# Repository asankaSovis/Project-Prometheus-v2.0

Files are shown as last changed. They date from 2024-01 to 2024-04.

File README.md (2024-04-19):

# 🔥 Project Prometheus v2.0
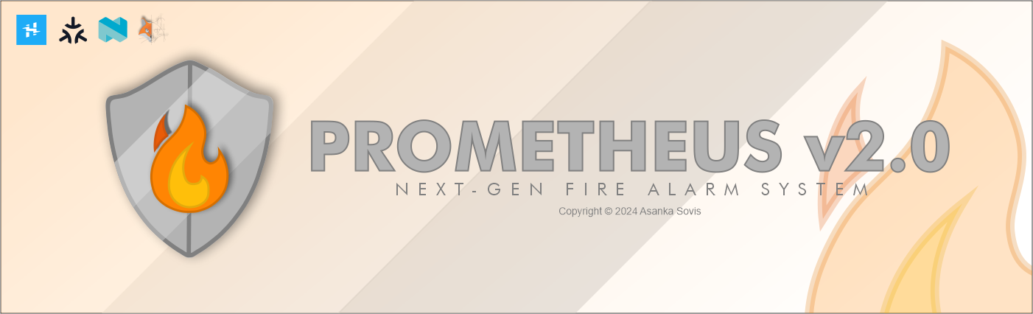
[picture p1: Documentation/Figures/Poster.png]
Poster

---

💸 Please consider donating on [Paypal](https://www.paypal.com/donate/?hosted_button_id=4EWXTWQ9FUFLA) to keep this project alive.

**Prometheus Fire Alarm System** is a fire alarm system and an extinguishing system that allows real-time monitoring via software. It can perform smart extinguishing on-site while simultaneously providing connectivity to multiple devices via the control panel. Prometheus is designed to be as simple and resilient as possible while making it safe to use and operate within a household.

**Prometheus 2.0** is the next generation of [Prometheus Fire Alarm System](https://github.com/asankaSovis/prometheus-fire-alarm); the future of household safety and monitoring. Developed on the nRF7002 platform, it brings all the features of v1.0 to the nRF platform along with additional features made possible by the nRF platform.

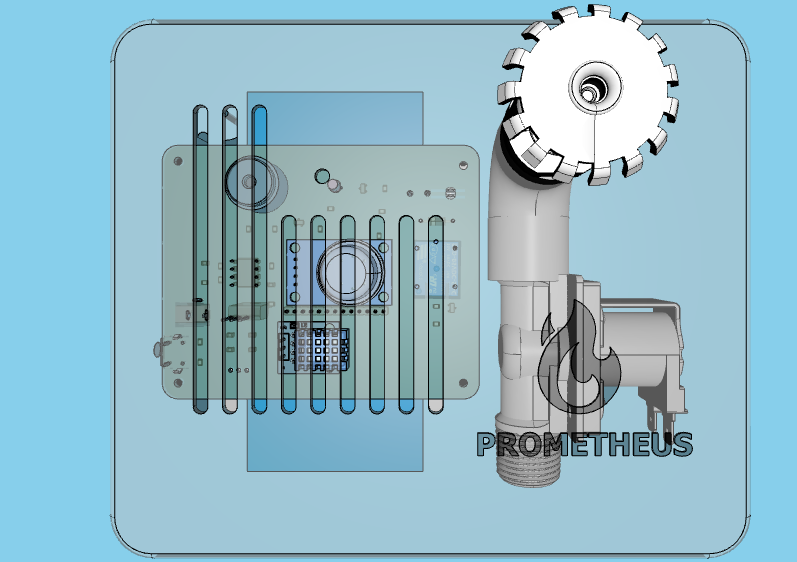
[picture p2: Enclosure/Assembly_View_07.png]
Assembly view
> 
> 3D view of the enclosure design

## 📜 License
> Project Prometheus v2.0 is licensed under the **GNU General Public License v3.0**.

Permissions of this strong copyleft license are conditioned on making available complete source code of licensed works and modifications, which include larger works using a licensed work, under the same license. Copyright and license notices must be preserved. Contributors provide an express grant of patent rights.

### Permissions
✔️ Commercial use | Modification | Distribution | Patent use | Private use

### Limitations
❌ Liability | Warranty

### Conditions
ℹ️ License and copyright notice | State changes | Disclose source | Same license 

Refer to the [License declaration](./LICENSE) for more details.

## 💾 Documentation
Please refer to the following links for different sections of documentation.

1. [Preface](./Documentation/Preface.md)
2. [Introduction](./Documentation/Introduction.md)
3. [Technical Specification](./Documentation/Technical_Specifications.md)
4. [Hardware Specification](./Documentation/Hardware_Specifications.md)
5. [Software Specification](./Documentation/Software_Specifications.md)
6. [Operational Details](./Documentation/Operational_Details.md)
7. [Project Management](./Documentation/Project_Management.md)
8. [Bill of Material](./Documentation/Bill_of_Material.md)
9. [References](./Documentation/References.md)
10. [Conclusion](./Documentation/Conclusion.md)

## 📊 Demonstration

> Prometheus Fire Alarm System - Demonstration (https://youtu.be/ORGNmy9aDy0 "Prometheus Fire Alarm System - Demonstration")
> Demonstration video of the final product

`© 2024 Asanka Sovis`

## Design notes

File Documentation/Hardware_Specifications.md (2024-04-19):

# Hardware Specification
The PCB of the Prometheus Fire Alarm System was designed and developed in-house. The PCB is a double layer PCB with sensors and indicators on the bottom and the rest of the components at the top. The PCB was manufactured and assembled by JLCPCB and the cost breakdown can be found in the [Bill of Material](./Bill_of_Material.md) section.
## Interface
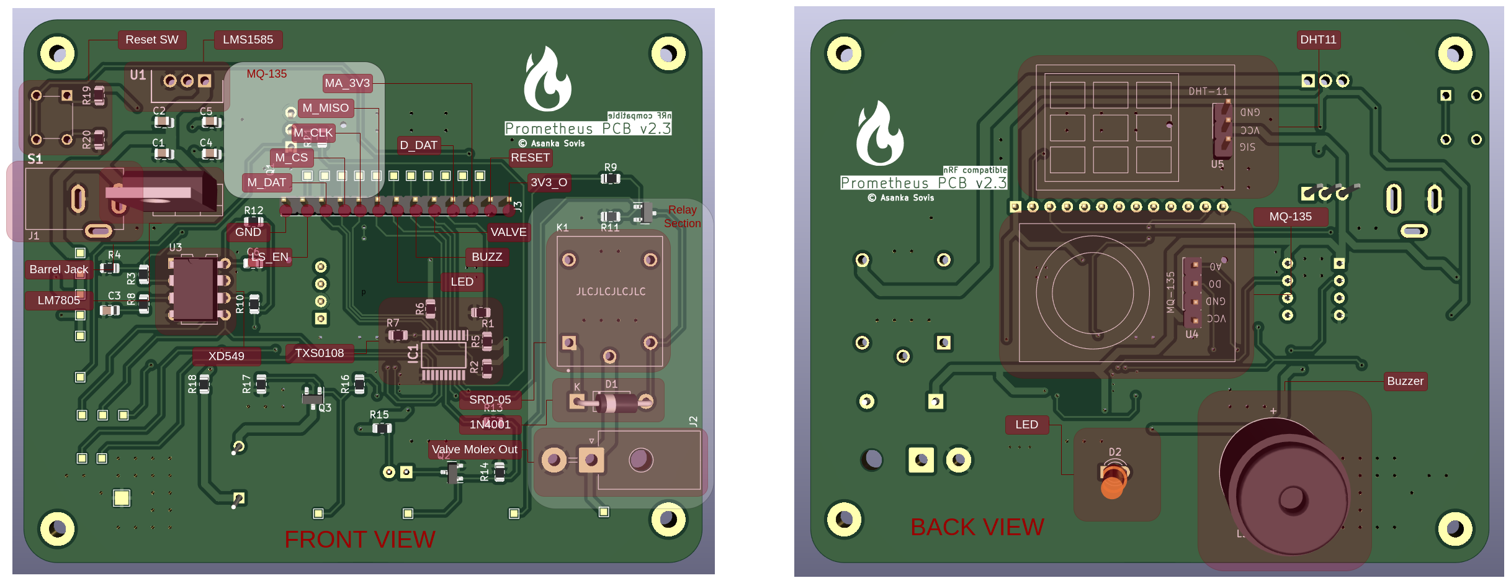
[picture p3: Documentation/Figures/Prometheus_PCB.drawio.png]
PCB layout on both sides
> 
> PCB layout on both sides

The interface between the Prometheus PCB and the nRF7002 DK is the most important part of the whole hardware design. This is why every control signal from the board is sent from a single location throughout the board. All of these signal have probing locations attached for debugging purposes. The pins are situated in the following order from left to right.

1. GND - Common ground.
2. LS_EN - Enable the level shifter. Active high, this pin has to be pulled up for the whole PCB to start working.
3. M_DAT - Digital out of the MQ-135 sensor. This is not used as the reading is sent through the ADC.
4. M_CS - Chip Select for the ADC recording the MQ-135 readings.
5. M_CLK - Clock signal for the ADC recording the MQ-135 readings.
7. M_MISO - Master In Slave Out for the ADC recording the MQ-135 readings.
8. LED - LED control signal.
9. BUZZ - Buzzer control signal.
10. VALVE - Valve control signal.
11. D_DAT - Data out of the DHT-11 sensor.
12. MA_3V3 - 5V analog output of the MQ-135 sent through a voltage divider to translate to a 3.3V output. This is here for experimental purposes and not used.
13. RESET - Reset signal from the reset button.
14. 3V3_O - 3.3V output to power the nRF7002 DK.

## Signalling
The nRF 7002 DK operates with standard 3.3V, however, the logic on the board is designed to operate in the 5V. This is because almost all the components used are 5V components. Thus all the logic goes through the TXS0108EQ Level Shifter. This translates the 3.3V signal from the nRF end to 5V on the PCB end and vice versa. The TXS0108EQ has the following structure.

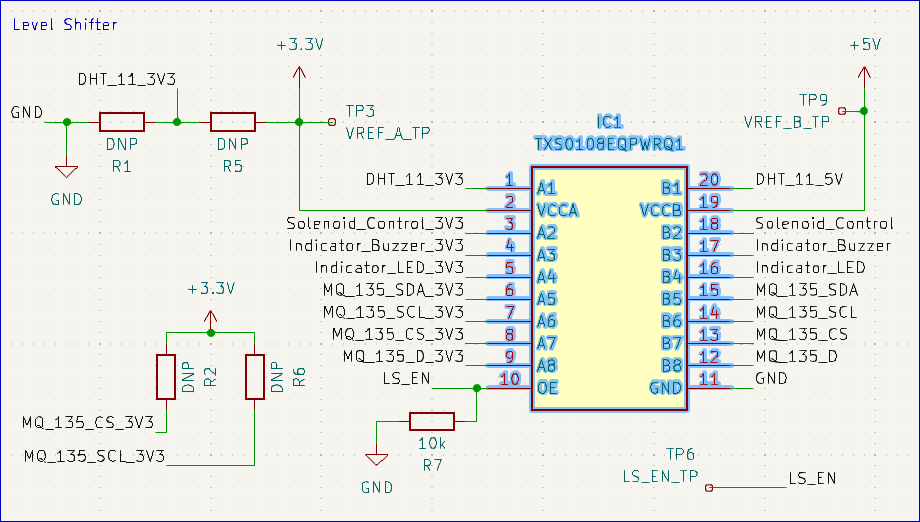
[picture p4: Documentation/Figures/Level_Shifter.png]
The structure of the level shifter layout on the PCB
> 
> The structure of the level shifter layout on the PCB

By enabling the chip by pulling the LS_EN up, we turn on the TXS0108EQ for communication with the PCB. Firmware details of this operation can be found in the [Software Specifications](./Software_Specifications.md) section.

## DHT-11 Reading
The DHT-11 uses UART to communicate with the controller. Therefore, the device only needs one data line to go to the microcontroller. As discussed, this line is simply routed through the level shifter to the nRF board.

## MQ-135 Reading
The MQ-135 is a bit more tricky. It has two signals coming out. One is the analog reading while the other is a digital one. Digital signal goes high when the analog signal reaches a certain threshold which can be set by the pot on the sensor itself. However, I wanted to get the analog reading to the nRF board and only use the digital pin as a backup.

Thus, the digital pin was simply routed through the level shifter and not used. This left me with the option of how to use the analog signal of the MQ-135. Using the ADC of the nRF means I have to step down the voltage to 3.3V which is not ideal for an analog signal. Therefore, I opted to use a voltage divider circuit just as another backup and sent this output directly to the nRF. However, if you check carefully, this is never used.

This is because I used a 5V ADC instead to take the reading of the MQ-135 and send it to the nRF as an SPI signal.

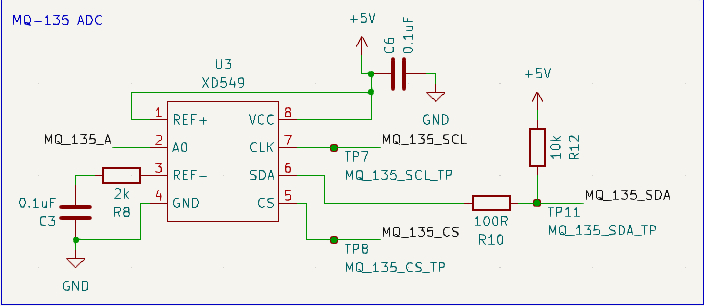
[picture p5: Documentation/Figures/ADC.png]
The XD549 ADC used for the MQ-135 analog signal
> 
> The XD549 ADC used for the MQ-135 analog signal

The XD549 is a 5V ADC and it sends the reading to the host controller as an SPI signal. For this we have three signal lines: CS, SDA (MISO) and CLK. Since the XD549 is a 5V device, these data lines have to be level shifted through the level shifter as well and since these are only carrying digital signals, there's no need to worry about shifting levels anymore. Firmware details of this operation can be found in the [Software Specifications](./Software_Specifications.md) section.

## Digital Output Devices
The PCB also features three digital IO devices. The buzzer and LED are quite straightforward and the circuit is simple. The signal from the nRF is passed through the level shifter to the IRLML6246 MOSFET and the MOSFET drives these two outputs.
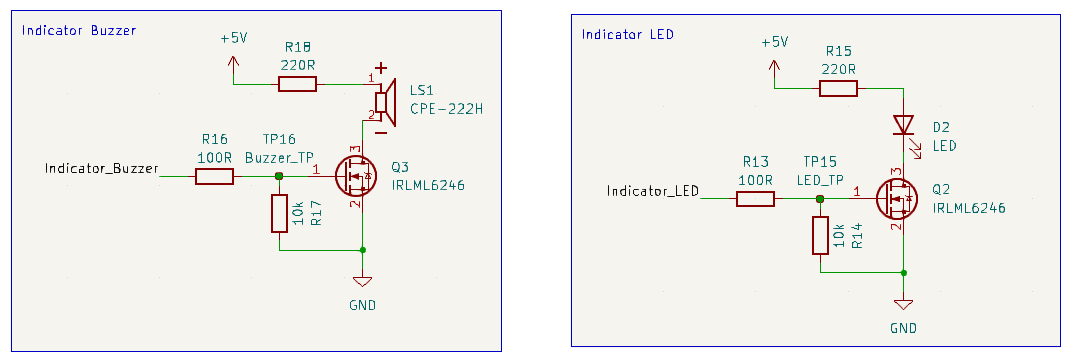
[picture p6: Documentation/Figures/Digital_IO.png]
Indicator LED and Buzzer design
> 
> Indicator LED and Buzzer design

The valve operates in pretty much the same way but the MOSFET does not drive the valve directly. The valve is a high current device and thus needs a relay for its operation. For this reason, the MOSFET drives a relay and that relay is what drives the valve in turn. The valve is connected via a MOLEX connector to the board.
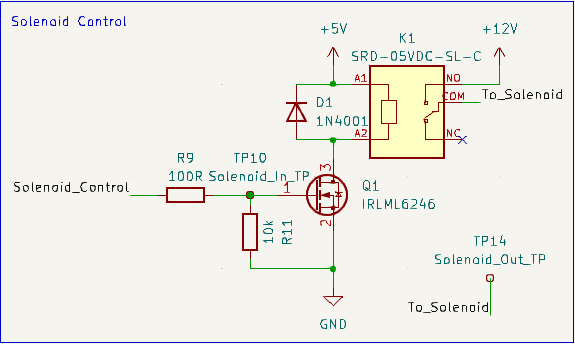
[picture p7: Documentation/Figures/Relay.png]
Valve control design
> 
>
> Valve control design

## Powering Up the System
The device needs to operate in three main voltage levels: 12V, 5V and 3.3V. The valve is controlled by a 12V signal, the nRF operates at 3.3V and the rest of the components operate at 5V. This means that 12V should come into the board as this is the highest required voltage level. In order to get the other two voltage levels, LM7805 and LMS1585 voltage regulators are used respectively for 5V and 3.3V. 
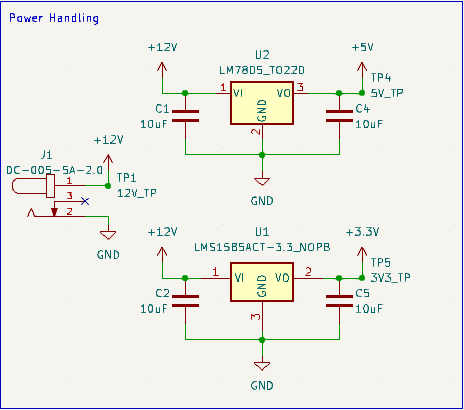
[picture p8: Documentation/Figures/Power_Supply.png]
Power supply for the PCB
> 
>
> Power supply for the PCB

The 12V can be provided through a 12V power supply and the device operates well below 500mA of current which makes it possible to use any 12V power supply. A typical power supply in this range comes with a barrel jack so the PCB has a barrel jack power input.

## Resetting the Device
The reset button simply connects the 3.3V to the reset of the nRF board. This allows for resetting the device from the PCB itself.

## The nRF 7002 DK
All required signals from the interface connect directly to the nRF 7002 DK as shown below.
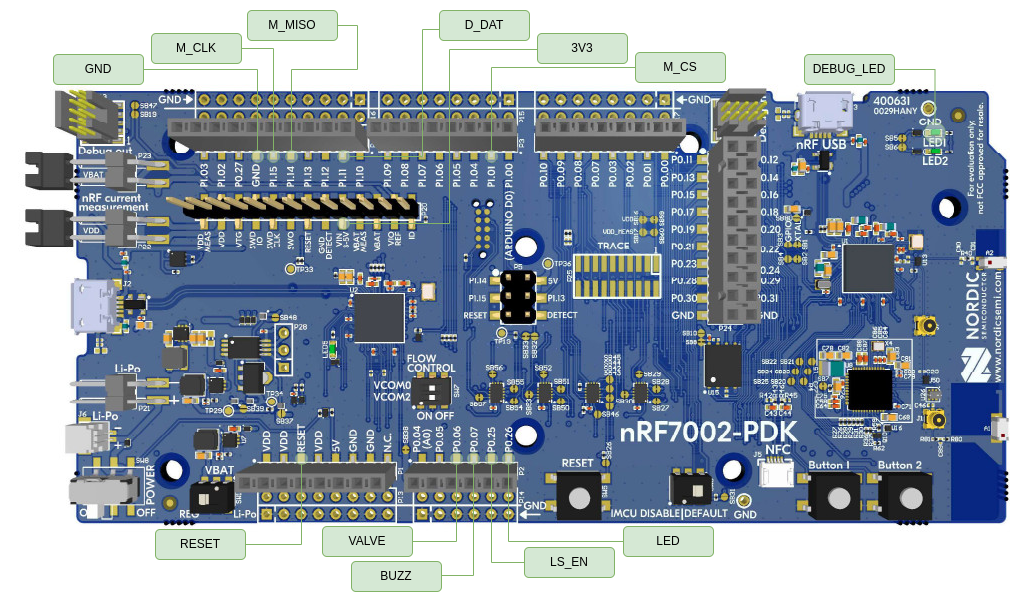
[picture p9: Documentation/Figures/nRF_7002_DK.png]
nRF 7002 DK interface pins
> 
> nRF 7002 DK interface pins *(Source: [developer.nordicsemi.com](https://developer.nordicsemi.com/nRF_Connect_SDK/doc/2.2.0/nrf/_images/nrf7002dk.jpg))*

The built-in LED 01 is also used for debug messaging. The default SPI line 3 of the SoC is used for the ADC while the rest of the GPIO was selected for convenience. 3.3V and GND from the power supply is also provided to the board from their respective pins. Additionally, the reset pin is also used however, in debug mode, this cannot be used. Firmware details of the operation of the nRF 7002 DK can be found in the [Software Specifications](./Software_Specifications.md) section.

## Schematic
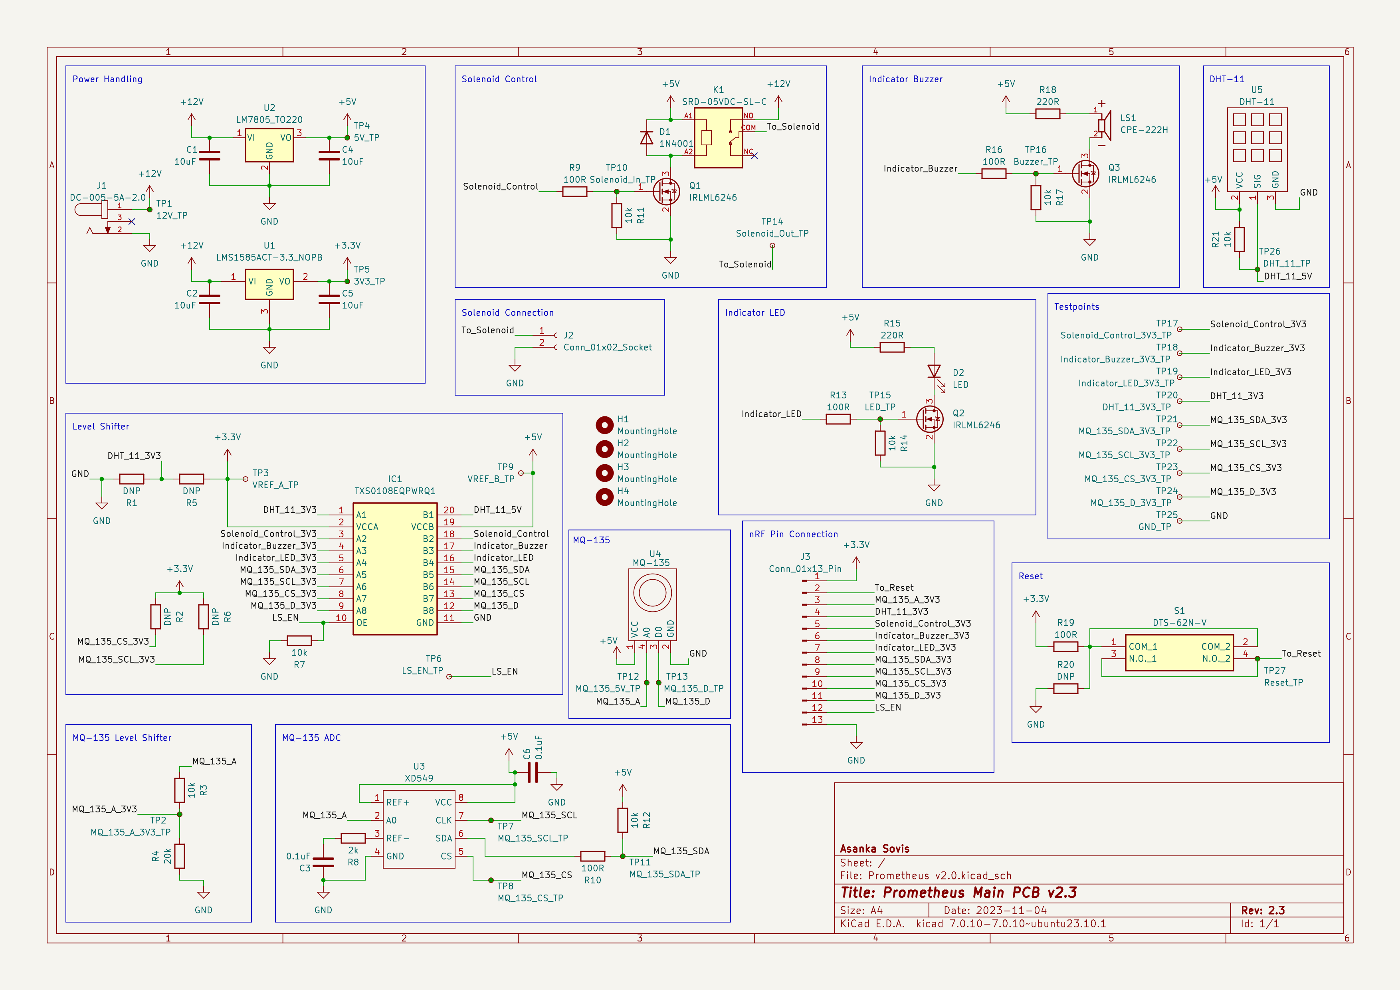
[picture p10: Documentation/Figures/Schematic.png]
The complete schematic view of the Prometheus PCB
> 
> The complete schematic view of the Prometheus PCB

The complete schematic of the PCB is given in the above diagram. This is available in the `Hardware/Prometheus v2.0` directory of the repository. The design was done using KiCad and all components used were available at JLCPCB at the time of manufacture. The complete Bill of Material and cost breakdown can be found in the [Bill of Material](./Bill_of_Material.md) section.

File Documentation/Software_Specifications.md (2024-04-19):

# Software Specification
The firmware of the Prometheus fire alarm system is developed entirely on the nRF Connect SDK. It uses Zephyr as the RTOS of choice and incorporates the device tree for hardware interfacing. It uses the SPI3 line of the nRF 5340 SoC for interfacing with the ADC. The rest of the IO connect to different signals in the PCB. The detailed breakdown is as follows.

- **GND -> GND** (Common grounding)
- **P1.15 -> M_CLK** (The clock of the  SPI 3 of the 5340 SoC to the Clock of the ADC)
- **P1.14 -> M_MISO** (MISO of the SPI 3 of the 5340 SoC to the SDA of the ADC)
- **P1.11 -> D_DAT** (Data signal from the DHT-11)
- **VIN 3-5V -> 3V3** (3.3V power supply to the nRF 7002 DK from the Prometheus PCB)
- **P1.01 -> M_CS** (Chip select GPIO from SoC to the CS of the ADC)
- **P0.26 -> LED** (GPIO to the LED control)
- **P0.25 -> LS_EN** (GPIO to the enable of the level shifter)
- **P0.07 -> BUZZ** (GPIO to the buzzer control)
- **P0.06 -> VALVE** (GPIO to the valve control)
- **RESET -> RESET** (Reset signal from the Prometheus PCB to the SoC)

The hardware layout of these pins within the Prometheus PCB and the nRF7002 DK can be found in the [Hardware Specifications](./Hardware_Specifications.md) section. Technical specification can be found in the [Technical Specifications](./Technical_Specifications.md). Additionally, the built-in LED 01 is used for debugging.

## Addressing and Configuration
The GPIO of the 5340 SoC has two 32bit GPIO addresses. Some of these are used internally, while the rest are usable. Each of the used pins are configured as follows.

- **P1.11** -> GPIO_PULL_UP | GPIO_ACTIVE_LOW
- **P0.25** -> GPIO_OPEN_SOURCE
- **P0.26** -> GPIO_OPEN_DRAIN
- **P0.06** -> GPIO_OPEN_DRAIN
- **P0.07** -> GPIO_OPEN_DRAIN
- **P1.01** -> GPIO_ACTIVE_HIGH | GPIO_OPEN_DRAIN

## Programming
The operation of the device starts with the initialization and checking if the device is ready. If not the built-in LED will periodically blink every second and try to reinitialize all components. Once done, the built-in LED will switch to flashing every ten second. At this stage, the sensor readings are read every 500ms and determined to see if critical levels are reached. If so, the warning is issued or valves are opened depending on the scenario. Additionally, if the user requested custom valve open or warning issue, this is also done. The operational flow chart of the device is given below.

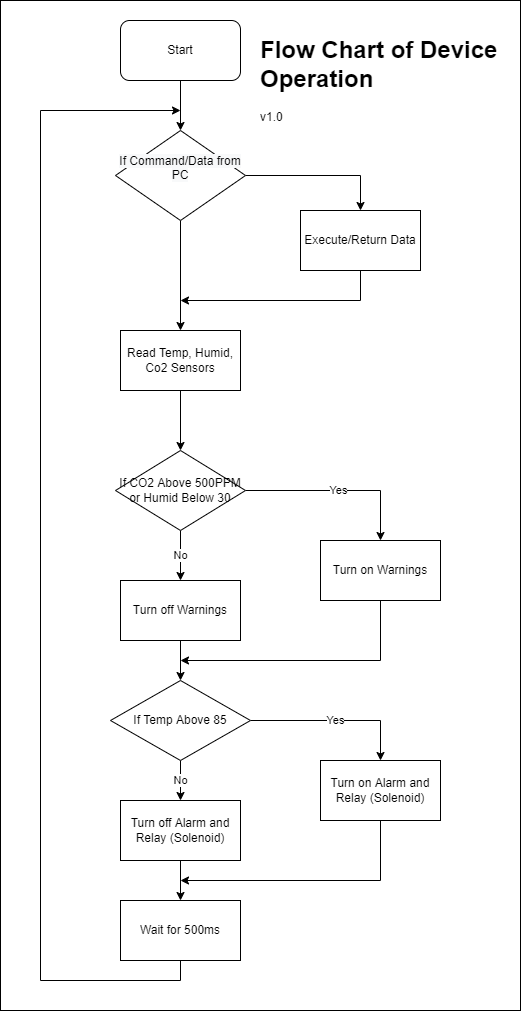
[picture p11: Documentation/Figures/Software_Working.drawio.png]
Operational flowchart of the device
> 
> Operational flowchart of the device

## Serial Protocol
The serial protocol is also an important aspect of the device. It allows the device to communicate with the Control Panel. All communication happen via the Micro USB interface of the nRF and USB port of a PC. The device communicate from its end via the COM ports while the device communicate from its end via the internal Zephyr UART. The communication is carried out in JSON. The communication protocol can be summed up as follows.
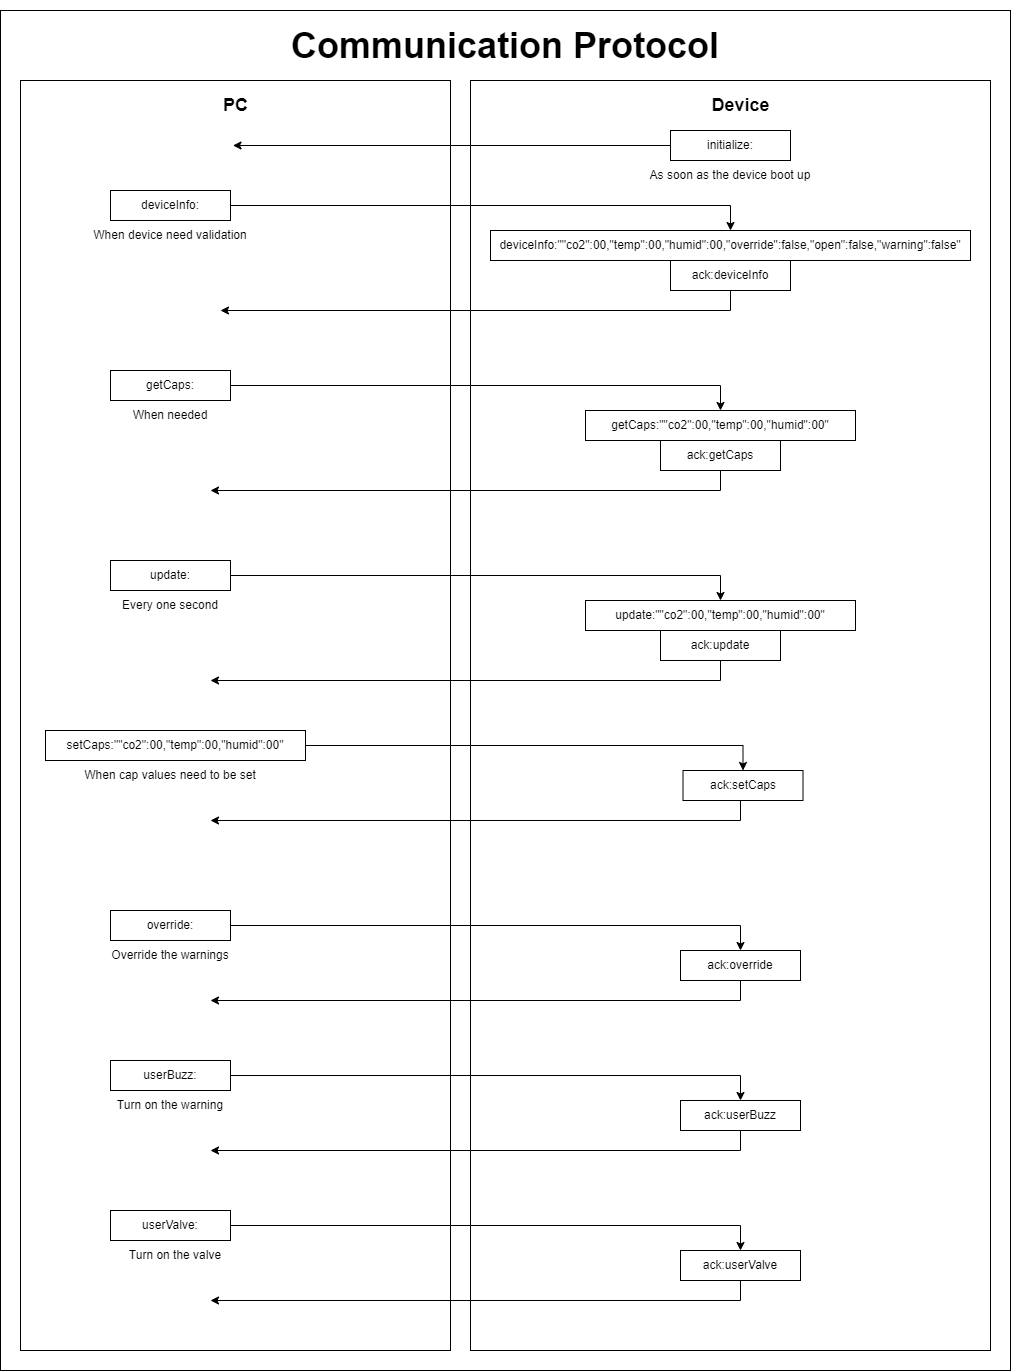
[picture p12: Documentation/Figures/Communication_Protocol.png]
Communication protocol
> 
> Communication protocol

## Monitoring and Controlling the Device
The Control Panel was written in C#. This program uses Windows APIs to connect to the COM ports of the computer to identify Prometheus devices connected. It has the following features.
- Connect multiple devices and add alias names to them for easy identification
- Monitor all sensor data from the devices from dedicated control panels
- Notifications for critical events
- Override warnings and control devices right from the PC
- Log sensor readings, visualize and export them
- Automatic reconnecting
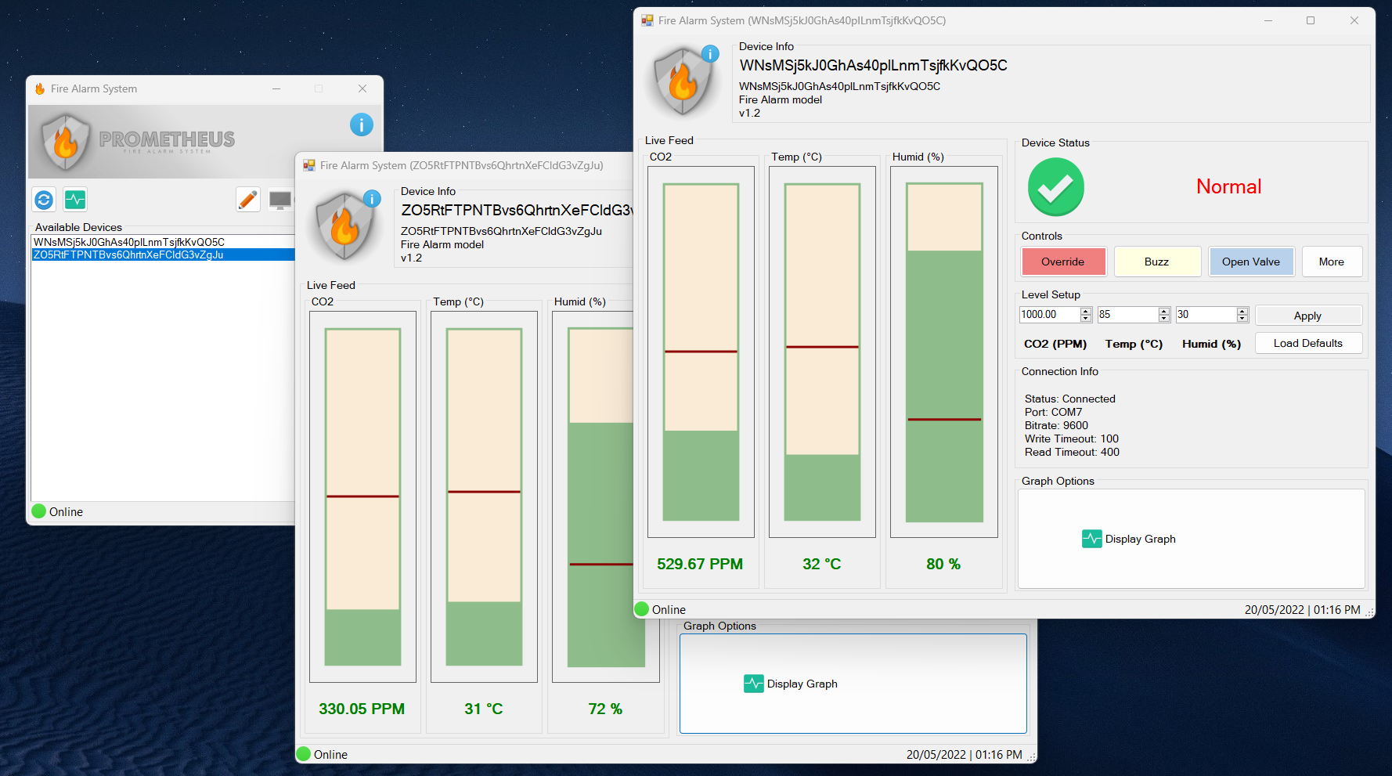
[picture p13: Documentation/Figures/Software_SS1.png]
> 
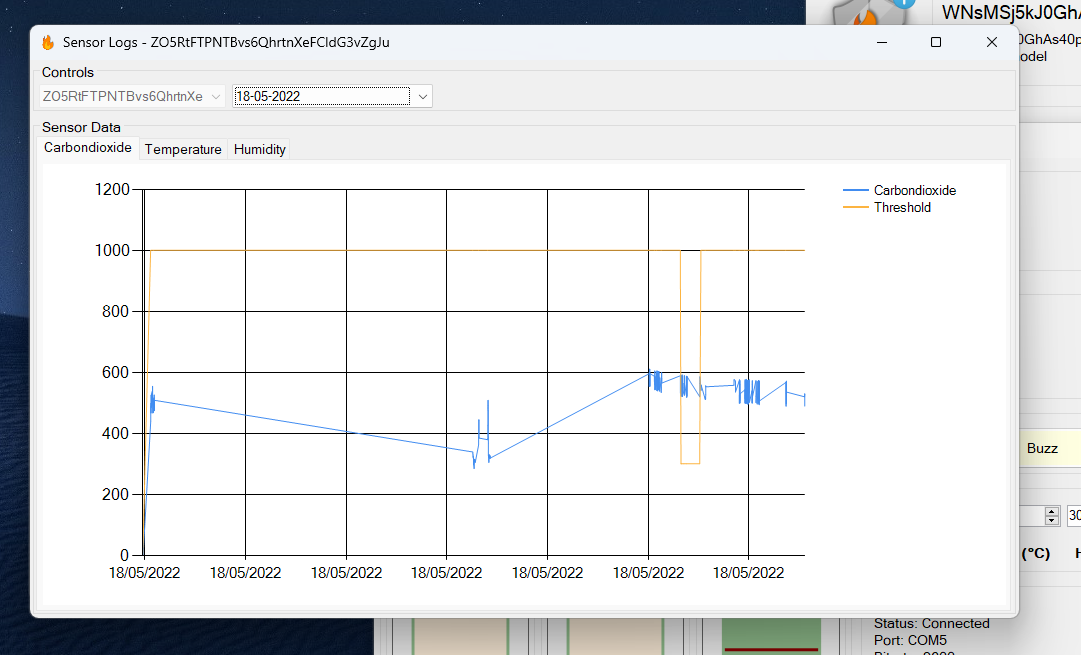
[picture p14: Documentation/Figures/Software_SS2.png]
> 
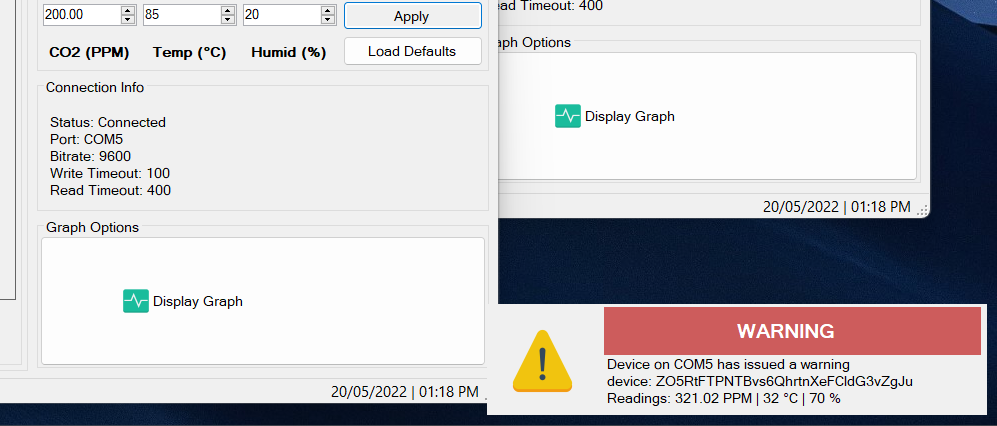
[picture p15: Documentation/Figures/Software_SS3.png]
> 
> Screenshots from the command panel

Further information on the project progress can be found in [Project Management](./Project_Management.md) section.

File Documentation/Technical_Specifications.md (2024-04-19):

# Technical Specifications
This section will discuss the overall technical specifications of the device. It includes each sensor/actuator/device categorized by what type of roll it performs along with the technical specifications. This section only includes the primary electronic items. For a comprehensive list of electronic components, please check the [Bill of Material](./Bill_of_Material.md). For operational details of the Prometheus Fire Alarm System, please refer to the [Operational Details](./Operational_Details.md) section.
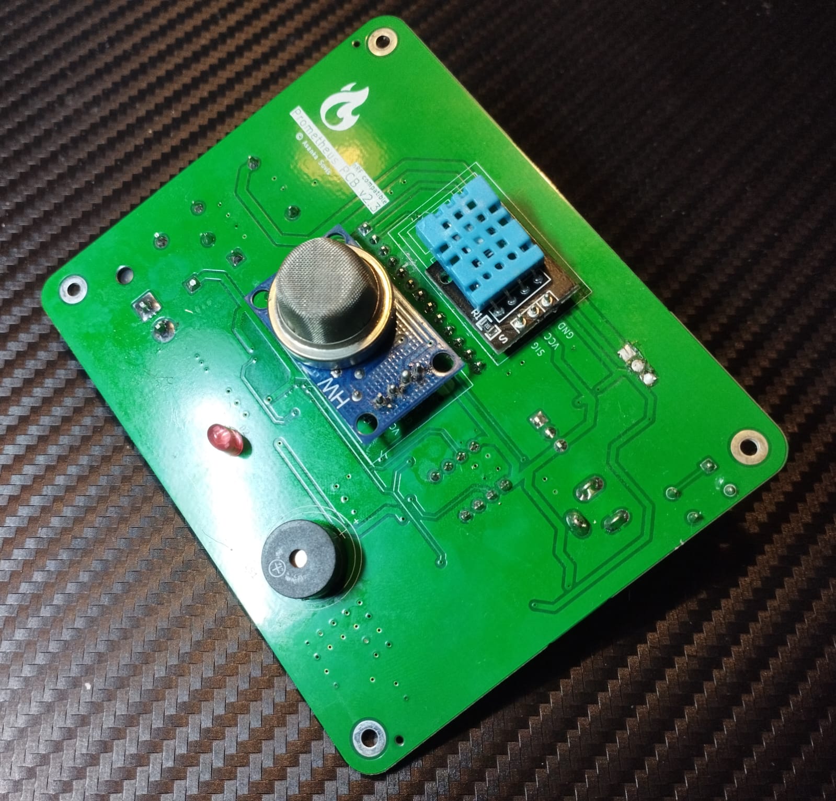
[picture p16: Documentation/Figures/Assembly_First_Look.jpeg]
First look at the assembly
> 
> First look at the assembly

## 1\. Control Unit
This is the brain of the system. It consists of an nRF7002dk which will be controlling the whole system. This also interfaces with all other components. With a dedicated nRF7002 Wi-Fi Companion IC and nRF5340 SoC, this is the ideal candidate for a project involving home automation and matter IoT device implementation.

### Specifications
#### nRF7002 - Low-power, advanced security, seamless coexistence
- 2\.4GHz and 5GHz Dual-band
- Low-power and Secure Wi-Fi for the IoT
- Ideal coexistence with Bluetooth LE
- Supported in nRF Connect SDK
- Wi-Fi 6 Station (STA)
- Complies with 802.11a/b/g/n/ac/ax
- 1 Spatial Stream (SS)
- 20 MHz channel bandwidth
- 64 QAM (MCS7), 86 Mbps PHY throughput
- OFDMA (Downlink and Uplink)
- BSS Coloring
- TWT
- SPI / QSPI
- Co-existence interfaces

#### nRF5340 SoC
- Dual-core Bluetooth 5.4 SoC supporting Bluetooth Low Energy, Bluetooth mesh, NFC, Thread and Zigbee
- 128 MHz Arm Cortex-M33 CPU with
- 1 MB Flash + 512 KB RAM
- 64 MHz Arm Cortex-M33 CPU with
- 256 KB Flash + 64 KB RAM
- Bluetooth Low Energy
- Bluetooth Direction Finding
- Bluetooth mesh
- Thread, Zigbee
- ANT
- NFC
- Advanced security
- USB, QSPI, HS-SPI
- 105 °C extended operating temperature
- 1\.7-5.5 V supply voltage range

## 2\. Fire Sensors
This is the module that directly interacts with the fire. This consists of two components as listed below.

### Specifications
#### Smoke Sensor – Detect the existence of a fire
- Operating Voltage: 2.5V to 5.0V
- Power consumption: 150mA
- Detect/Measure: NH3, Nox, CO2, Alcohol, Benzene, Smoke
- Typical operating Voltage: 5V
- Digital Output: 0V to 5V (TTL Logic) @ 5V Vcc
- Analog Output: 0-5V @ 5V Vcc

#### Temperature and Humidity Sensor – Detect the thermal changes in the surrounding
- Operating Voltage: 3.5V to 5.5V
- Operating current: 0.3mA (measuring) 60uA (standby)
- Output: Serial data
- Temperature Range: 0°C to 50°C
- Humidity Range: 20% to 90%
- Resolution: Temperature and Humidity both are 16-bit
- Accuracy: ±1°C and ±1%

They will sense the following three from the environment.
- Temperature – DHT11 sensor
- Humidity – DHT11 sensor
- Carbondioxide – MQ 135 sensor

DHT 11 communicates with the microcontroller digitally using UART while the MQ 135 senses analog and translates it to an SPI message via the ADC.

## 3\. Extinguisher
The extinguisher consists of three parts. It handles the extinguishing of the fire.

### Specifications
#### 5V relay – Convers the 5V control signal to 12V so that the solenoid valve can operate
- Supply voltage: 3.75V to 6V
- Quiescent current: 2mA
- Current when the relay is active: \~70mA
- Relay maximum contact voltage: 250VAC or 30VDC
- Relay maximum current: 10A

#### Solenoid Valve – Controls the water flow
- Material: Metal + plastic
- Voltage: DC 12V
- Power: 15W
- Current: 1.25A
- Inlet and outlet thread diameter: G1/2
- Pressure: 0.02 - 0.8Mpa
- Max fluid temperature: 80°C
- Operation mode: Normally Closed

#### Nozzle – Sprays the water onto the fire so that the extinguishing is effective
While the relay and valve were bought, the nozzle was custom-fabricated to suit the needs.

## 4\. Indicators
The indicators give an indication to the people about the fire. We included two indicators, both visual and auditory for the best outcome.

### Specifications
#### Visual – nRF7002dk Built-In LED
This LED indicates the technical status of the device. While initializing, the LED with be turned on. Once successful, it will flash every second to indicate that the device is actively monitoring. On an error, the LED will blink every second to indicate an error in the device.

#### Visual – Indicator red LED
The red LED will blink twice every second to indicate that the system is operating normally. If it stays continuously on, then there is a warning or extinguishing has started. Any other combination or no light at all means that the device is turned off or is not working properly.

#### Auditory – A 5V Buzzer
The buzzer stays off when the system is operating normally. It will beep once every second in case a warning is issued. It will then continuously buzz in case of an extinguishing.

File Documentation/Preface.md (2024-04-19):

# Preface
One of the key requirements for a smart home is the safety and well-being of the inhabitants.  This is why it's important to have devices to actively monitor and rectify any threats that occur within the house. One such threat is the hazard of fire. According to the WHO, more than 300,000 deaths occur every year due to fire-related hazards [1](https://scholar.google.com/scholar_lookup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,+1991-1995&author=CfD+Control&volume=47&issue=38&publication_year=1998&pages=803-6&pmid=9776167&).

Thus we see the importance of incorporating a fire monitoring and extinguishing system into the modern smart home. This should actively monitor the environment for critical changes in the levels of humidity, temperature and carbon dioxide and take necessary precautions to rectify any fires that get detected. The residents should also get the convenience of actively monitoring the state of the alarm and extinguishing system whenever they require it. This is the premise of the Prometheus Fire Alarm System v2.0.

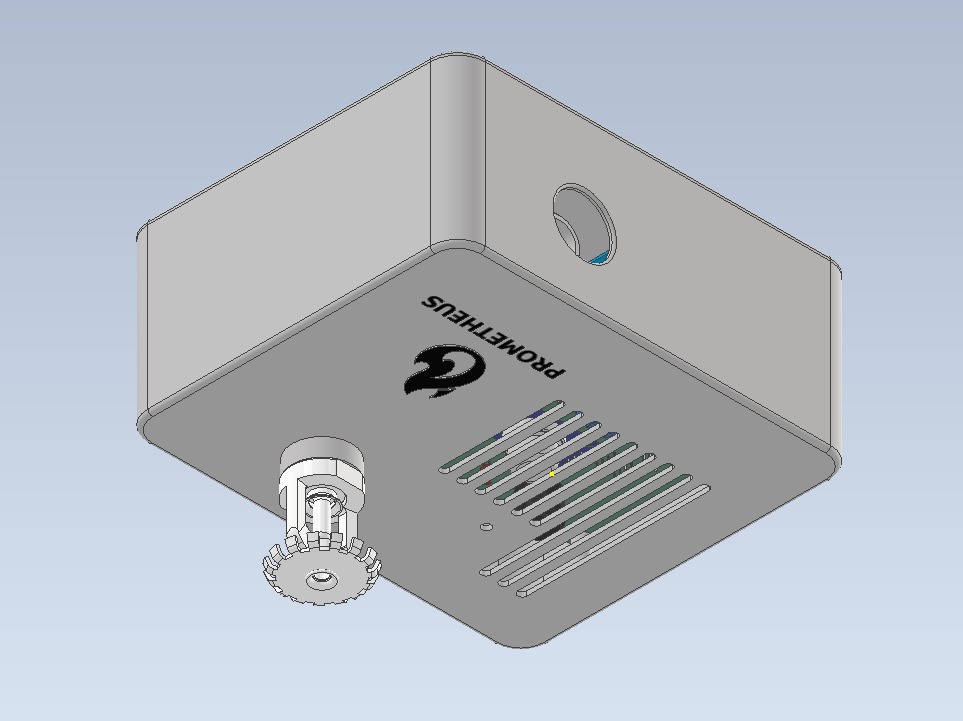
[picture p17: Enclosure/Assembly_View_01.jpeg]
Final assembly render
> 
> Final assembly render

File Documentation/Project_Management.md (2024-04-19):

# Project Management
## Development So Far
The project started with a proposal outlining the problem, intended solution and its development strategy. This can be found in the [Project Prometheus v2.0](./Project_Prometheus_v2.0.md) document. Using this, hardware request was applied on September 20, 2023. On September 25, 2023 an email was received with the news that the Prometheus Fire Alarm System v2.0 was selected as a recipient for free hardware.

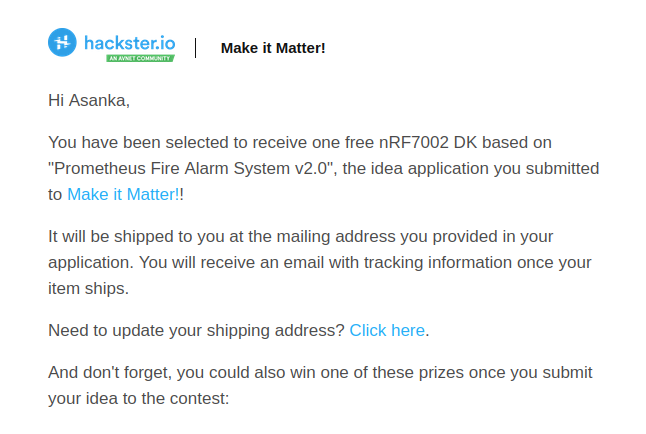
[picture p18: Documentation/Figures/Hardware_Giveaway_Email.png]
Email received announcing the selection to receive hardware
> 
> Email received announcing the selection to receive hardware

With this, a project timeline was created to better optimize the limited time I have. 

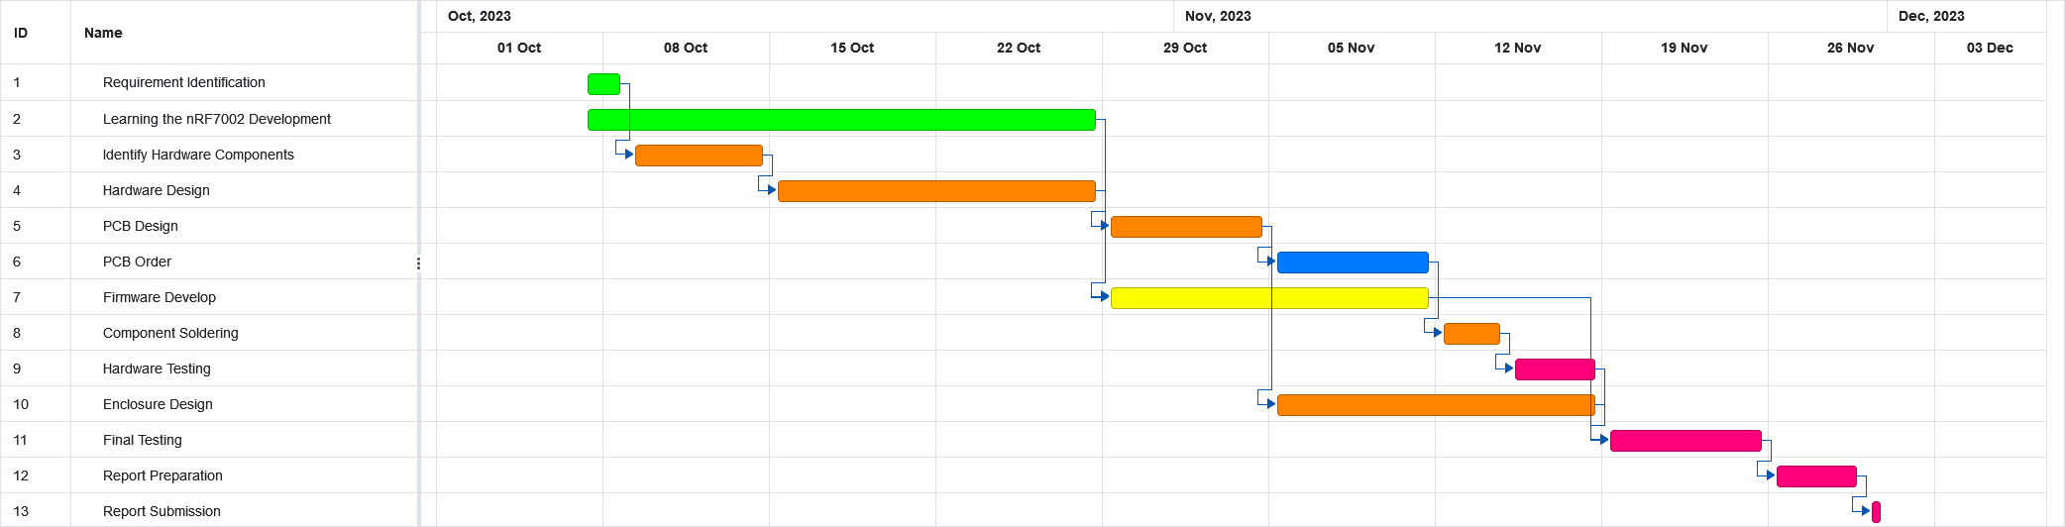
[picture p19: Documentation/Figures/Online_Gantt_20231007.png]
Project timeline
> 
> Project timeline

However, keeping up with this schedule proved to be extremely hard as I was treading in new territory. Thanks to the extension provided until January 14, 2024, the project managed to continue on. The final report was submitted on January 14, 2024.

## Project Status
After the final submission of the report, the state of the project is as follows.

- Requirement identification ✔️
- Learning the nRF 7002 development ♻️
- Identify hardware components ✔️
- Hardware design ✔️
- PCB design ✔️
- PCB order ✔️
- Firmware development ✔️
- Integrating matter protocol ♻️
- Component soldering ✔️
- Hardware testing ✔️
- Enclosure design ✔️
- Final testing  ♻️
- Report preparation ✔️
- Report submission ✔️

## Identified Issues with the Project
The following issues are mainly highlighted after analyzing the current state of the project.

- Unpublished articles in the Hashnode backlog
- Damaged MQ-135 sensor while hardware testing
- Matter integration incomplete
- Not enough knowledge and experience with nRF
- Not enough testing completed

## Future of the Project
After a small break from the project, my plan is to start rectifying these issues and adding more features to the design.

- Complete the [nRF Connect SDK Fundamentals](https://academy.nordicsemi.com/courses/nrf-connect-sdk-fundamentals/) course
- Complete integrating matter protocol to the project
- Replace MQ-135 gas sensor
- Replace DHT11 with Bosch BME280
- Publish and complete backlog of Hashnode articles
- Continue testing the system
- Write redesigned command panel using Flutter to be cross-platform and supporting both serial communication and matter network

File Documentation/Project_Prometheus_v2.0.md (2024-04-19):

# Introduction
One of the key requirements for a smart home is the safety and well-being of the inhabitants.  This is why it's important to have devices to actively monitor and rectify any threats that occur within the house. One such threat is the hazard of fire. According to the WHO, more than 300,000 deaths occur every year due to fire-related hazards [1].

Thus we see the importance of incorporating a fire monitoring and extinguishing system into the modern smart home. This should actively monitor the environment for critical changes in the levels of humidity, temperature and carbon dioxide and take necessary precautions to rectify any fires that get detected. The residents should also get the convenience of actively monitoring the state of the alarm and extinguishing system whenever they require it. This is the premise of the Prometheus Fire Alarm System v2.0.

## Prometheus v1.0
The idea of a fire alarm system has already been implemented in the form of Prometheus Fire Alarm System v1.0. This version aimed at developing a cost-effective monitoring and extinguishing system that is robust and scalable. The following were the targets of this project:

1. **Cost** - Develop a system based on off-the-shelf components that are cost-effective
2. **Scalable** - Availability for multiple monitoring devices to operate and synchronize in real-time
3. **Independent** - Whether connected or not, the device should monitor and react on its own without the involvement of the operator

## What's Next?
The next step would be to improve the Prometheus Fire Alarm System into a smart home device, bringing in the cost-effective, independent and scalable fire alarm and extinguishing system to the smart home. This will allow it to sit alongside other sensors and systems to provide all the smart homes with safety from fire.

The improvements thus suggested will be as follows.

1. Add a built-in charging system to allow the system to run when even the power is lost
2. Redesign the system to use the **nRF7002** chip instead of an ATMega
3. Rewrite the firmware to incorporate the Matter protocol

## Further Information
[Prometheus Fire Alarm System Firmware Repo](https://github.com/asankaSovis/prometheus-fire-alarm/tree/main)
[Prometheus Command Panel Repo](https://github.com/asankaSovis/prometheus-command-panel)
[Prometheus Fire Alarm System v1.0 Report](https://github.com/asankaSovis/prometheus-fire-alarm/blob/main/Additional%20Material/Engineering%20Design%20Project%20-%20Project%20Report.pdf)
[Prometheus Fire Alarm System Demo Video (Youtube)](https://youtu.be/5h3k6kufkHo?si=pq6S2FBMBYGGU_1R)

## References
[1] https://scholar.google.com/scholar_lookup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,+1991-1995&author=CfD+Control&volume=47&issue=38&publication_year=1998&pages=803-6&pmid=9776167&
[2] https://www.co2meter.com/blogs/news/15164297-co2-gas-concentration-defined
[3] https://science.howstuffworks.com/environmental/earth/geophysics/fire.htm

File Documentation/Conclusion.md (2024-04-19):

# Conclusion
Project Prometheus v2.0 turned into such an exciting and inspiring pet project for me. It encouraged me to learn so many new things and to experiment with things that I never would've had access to before. On this submission day, I'm confident about what I managed to achieve with this project. Prometheus came so far; yet there's more to look forward to. I'm excited and looking forward to seeing where Project Prometheus will go in the future. After a small break, I will be back with its development.

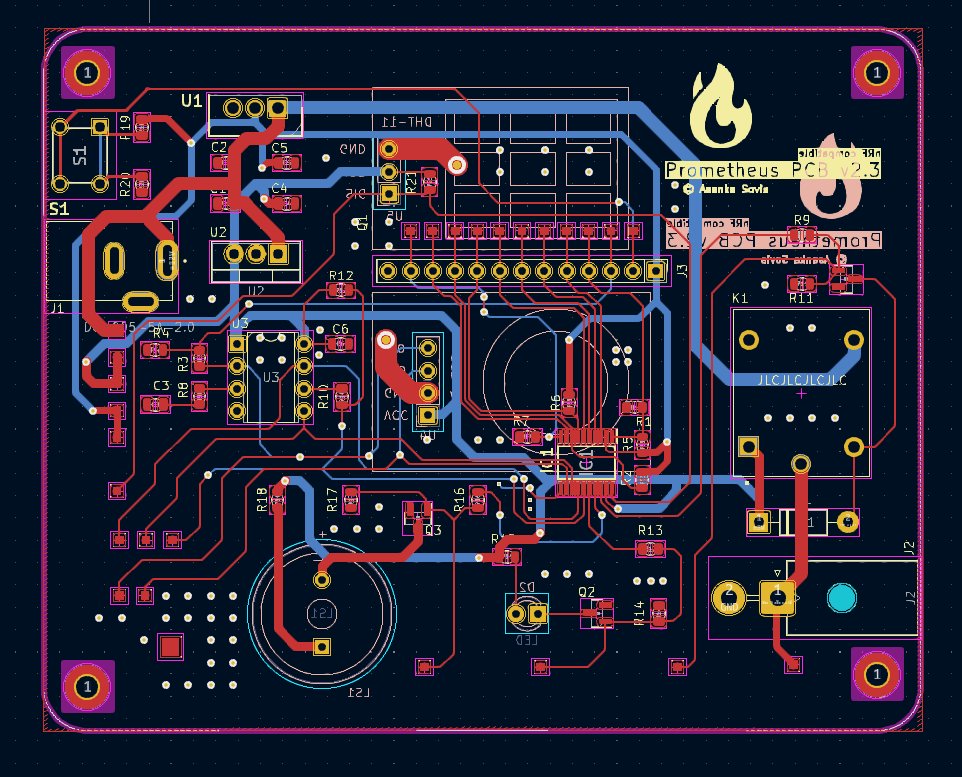
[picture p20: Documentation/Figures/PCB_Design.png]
> 
> View of the PCB design of Prometheus PCB

## Thanks
This four-month journey was a journey filled with a lot of ups and downs. I would not be able to achieve this level of improvement without the help of countless people. The biggest support came from the people at my former workplace who encouraged, advised, continuously asked about the progress and even offered technical guidance and help.
This goes without mentioning the awesome people who helped me whenever I posted dumb questions on the [Nordic DevZone](https://devzone.nordicsemi.com/) forum and Discord server. Thank you for tolerating my newbie questions and annoying mistakes.

Thanks to the people who had been posting content on Youtube and other platforms guiding people through Matter, the nRF platform, Zephyr and related fields. Without you, this project would not be able to flourish.
Finally to the awesome people at Nordic Semiconductors and Hackster.io for organizing such a valuable opportunity. I would never have been able to afford to own something like nRF7002 DK if not for this project. Thank you for allowing me to enter into this world of innovative technology.

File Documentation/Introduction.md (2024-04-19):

# Introduction
> 3D view of the enclosure design
> 3D view of the enclosure design

**Prometheus Fire Alarm System** is a fire alarm system and an extinguishing system that allows real-time monitoring via software. It can perform smart extinguishing on-site while simultaneously providing connectivity to multiple devices via the control panel. Prometheus is designed to be as simple and resilient as possible while making it safe to use and operate within a household.

**Prometheus 2.0** is the next generation of [Prometheus Fire Alarm System](https://github.com/asankaSovis/prometheus-fire-alarm); the future of household safety and monitoring. Developed on the nRF7002 platform, it brings all the features of v1.0 to the nRF platform along with additional features made possible by the nRF platform.

> First demo of the Prometheus Fire Alarm System v2.0 in operation (https://youtu.be/ORGNmy9aDy0 "Prometheus Fire Alarm System - Demonstration")
> First demo of the Prometheus Fire Alarm System v2.0 in operation

## Project Overview
The project spanned from October 5, 2023, to January 14, 2024. Since, enrolling on the project, I have been tirelessly working on the development of the Prometheus Fire Alarm System. Since its inspection, it has been one of my pet projects that I did in my free time after completing it as a project for the university. It brought me a lot of knowledge, experience and fun. The Make it Matter contest had been a great opportunity for me to share my pet project with the world, and to integrate it with a well-renowned platform such as the nRF platform.
Juggling between academic work, full-time employment and personal life, I am proud of my achievements. However that I have come up with. However, I still feel like there's a long way for Prometheus to go.

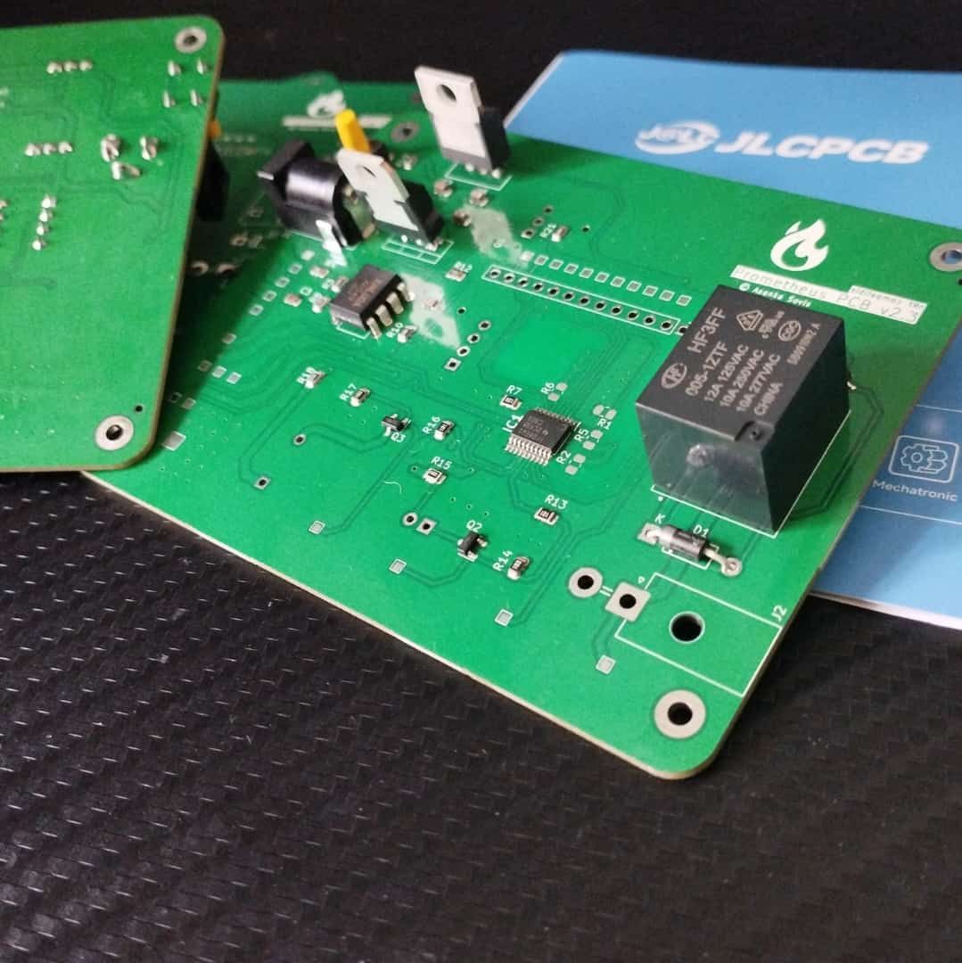
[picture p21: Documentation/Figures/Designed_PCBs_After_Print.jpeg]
First look at the Prometheus PCB v2.0 after arriving from JLCPCB
> 
> First look at the Prometheus PCB v2.0 after arriving from JLCPCB

## The Journey and the Future
The journey started without any idea about Nordic, nRF or Matter. With limited access to resources and a limited budget, the project continued with days of researching online to discussing in online forums. However, with this limited budget and time, I am proud of what I've achieved. It had been a great opportunity to work with the nRF platform.

This will not be the end of my journey with Nordic or the nRF platform as I have planned to continue the devlog of the Prometheus Project. I also have tutorials planned on the issues I faced while working on this platform. One of the biggest hurdles I faced was the limited availability of resources online and outdated information. nRF and Matter are evolving rapidly but the internet has not yet been able to keep up with this growth and expansion. I'd like to pay my part and share my knowledge with others in hopes that they might not run into the same issues that I had to face.

In terms of Project Prometheus, there is a lot of work planned, even after the end of the **Make it Matter** contest. And I welcome everyone to continue the journey on [my Blog](https://asanka.hashnode.dev/).

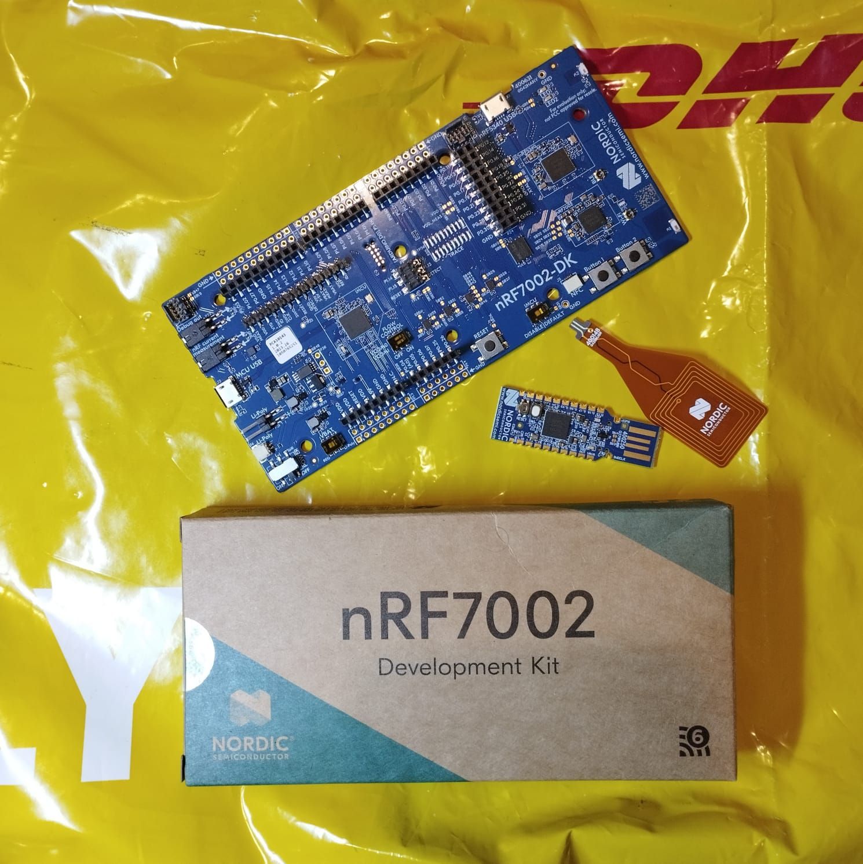
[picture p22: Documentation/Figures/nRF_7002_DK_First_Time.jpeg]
First look at the nRF7002 DK
> 
> First look at the nRF7002 DK

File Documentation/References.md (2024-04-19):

# References
## Internal References

- [Prometheus Fire Alarm System v2.0 - First Prototype](https://youtu.be/ORGNmy9aDy0?si=K__lnq3Fp0OjW0Gl)
- [Project Prometheus v2.0 Repository](https://github.com/asankaSovis/Project-Prometheus-v2.0)
- [Prometheus Fire Alarm System Repository](https://github.com/asankaSovis/prometheus-fire-alarm)
- [Prometheus Command Panel](https://github.com/asankaSovis/prometheus-command-panel)
- [Asanka Sovis - Github Profile](https://github.com/asankaSovis)
- [Asanka Sovis - Website](https://asankasovis.github.io/)
- [Asanka Sovis - LinkTree](https://linktr.ee/asankasovis)
- [Asanka Sovis - LinkedIn](https://www.linkedin.com/in/asanka-sovis/)
- [Asanka Sovis - X (Formerly Twitter)](https://twitter.com/AsankaSovis)
- [Asanka Sovis - Hashnode Blog](https://asanka.hashnode.dev/)
- [Asanka Sovis - Blogspot](https://asanka-sovis.blogspot.com/)
- [Asanka Sovis - Hackster.IO Profile](https://www.hackster.io/AsankaSovis)

## External References
- [Getting started with nRF7002 DK](https://developer.nordicsemi.com/nRF_Connect_SDK/doc/2.2.0/nrf/ug_nrf7002.html)
- [Zephyr Project Documentation](https://docs.zephyrproject.org/latest/index.html)
- [Hackster.IO - Make It Matter Contest](https://www.hackster.io/contests/makeitmatter)
- [Alphatronic Store](https://alphatronic.lk/)
- [Nordic DevZone](https://devzone.nordicsemi.com/)
- [nRF Connect SDK Documentation](https://infocenter.nordicsemi.com/index.jsp?topic=%2Fug_nrf7002_dk%2FUG%2Fnrf7002_DK%2Fintro.html)
- [JLCPCB SMT Parts Library](https://m.jlcpcb.com/more/partsLibrary)
- [nRF 5340 SoC Documentation](https://www.nordicsemi.com/Products/nRF5340)
- [nRF7002 Wi-Fi 6 Companion IC Documentation](https://www.nordicsemi.com/Products/nRF7002)
- [nRF7002 DK Documentation](https://www.nordicsemi.com/Products/Development-hardware/nRF7002-DK)
- [Matter over Thread with NRF52](https://abluethinginthecloud.com/matter-over-thread-with-nrf52/)
- [Circuit Dojo Youtube Channel](https://www.youtube.com/@CircuitDojo)
- [The Linux Foundation Youtube Channel](https://www.youtube.com/@LinuxfoundationOrg)
- [The Zephyr Project Youtube Channel](https://www.youtube.com/@ZephyrProject)
- [Nordic Semiconductor Youtube Channel](https://www.youtube.com/@NordicSemi)
- [WSN & IoT Youtube Channel](https://www.youtube.com/@wsniot)
- [nRF Connect SDK Fundamentals](https://academy.nordicsemi.com/courses/nrf-connect-sdk-fundamentals/)

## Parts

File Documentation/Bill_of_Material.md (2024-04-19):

# Bill of Material
This includes a comprehensive list of all the individual electronic and non-electronic components used in the manufacture of the Prometheus Fire Alarm System. For an overall specification of the sensors, actuators and controllers; please refer to the [Technical Specifications](./Technical_Specifications.md) section.

1. [10uF Capacitors](<## 10uF Capacitors - Quantity 4>)
2. [0\.1uF Capacitors](<## 0.1uF Capacitors - Quantity 2>)
3. [10kΩ Resistors](<## 10kΩ Resistors - Quantity 7>)
4. [100Ω Resistors](<## 100Ω Resistors - Quantity 5>)
5. [220Ω Resistors](<## 220Ω Resistors - Quantity 2>)
6. [20kΩ Resistors](<## 20kΩ Resistors - Quantity 1>)
7. [2kΩ Resistors](<## 2kΩ Resistors - Quantity 1>)
8. [1N4001 Diode](<## 1N4001 Diode - Quantity 1>)
9. [Through Hole LED](<## Through Hole LED - Quantity 1>)
10. [LMS1585 Voltage Regulator](<## LMS1585 Voltage Regulator - Quantity 1>)
11. [LM7805 Voltage Regulator](<## LM7805 Voltage Regulator - Quantity 1>)
12. [XD549 ADC](<## XD549 ADC - Quantity 1>)
13. [MQ-135 Gas Sensor](<## MQ-135 Gas Sensor - Quantity 1>)
14. [DHT-11 Temperature/Humidity Sensor](<## DHT-11 Temperature/Humidity Sensor - Quantity 1>)
15. [IRLML 6246 MOSFET](<## IRLML 6246 MOSFET - Quantity 3>)
16. [TXS0108EQ Level Shifter](<## TXS0108EQ Level Shifter - Quantity 1>)
17. [SRD-05 Relay](<## SRD-05 Relay - Quantity 1>)
18. [CPE-222H Buzzer](<## CPE-222H Buzzer - Quantity 1>)
19. [DTS-62 Horizontal Switch](<## DTS-62 Vertical Switch - Quantity 1>)
20. [XKB DC-005 Barrel Jack Connector](<## XKB DC-005 Barrel Jack Connector - Quantity 1>)
21. [2x1 Molex Connector](<## 2x1 Molex Connector - Quantity 1>)
22. [1x13 Pin Header](<## 1x13 Pin Header - Quantity 1>)
23. [nRF 7002 DK Development Board](<## nRF 7002 DK Development Board - Quantity 1>)
24. [12V Power Supply with DC Barel Jack](<## 12V Power Supply with DC Barel Jack - Quantity 1>)
25. [Micro USB Cable](<## Micro USB Cable - Quantity 1>)
26. [1x13 Male to Female Ribbon Cable](<## 1x13 Male to Female Ribbon Cable - Quantity 1>)
27. [ZE-4F180 Valve with compatible tubing and spray end](<## ZE-4F180 Valve with compatible tubing and spray end - Quantity 1>)

## Cost Breakdown
The nRF 7002 DK was recieved from the hardware giveaway program saving me around $56.49. (Rs. 18, 189.30) The direct cost was only involved with PCB manufacturing, assembly and shipping. Overall, the cost breakdown is as follows.
- nRF 7002 DK: $0.00
- PCB Printing: $4.00
- Setup fee: $8.00
- Stencil: $1.50
- Components: $15.12
- Extended components fee: $25.48
- SMT Assembly: $0.46
- Hand-soldering labor fee: $3.50
- Manual Assembly: $0.96
- Refund: -$0.06

This adds a merchandise total of $58.96 (Rs. 18, 984.62)
- MERCHANDISE TOTAL: $58.96 (Rs. 18, 984.62)
- SHIPPING CHARGE: $25.90 (Rs. 8, 339.58)
- DISCOUNT: - $10.00 (Rs. 3, 219.92)
- ORDER TOTAL: $74.86 (Rs. 24, 104.28)

This finally gives a total of $74.86 (Rs. 24, 104.28). Adding government taxes of Rs. 8, 000 ($24.85) gives a final expense of $99.71 (Rs. 32, 104.28).
- ORDER TOTAL: $74.86 (Rs. 24, 104.28)
- GOVERNMENT TAXES: $24.85 (Rs. 8, 000)

- **FINAL DIRECT COST: $99.71 (Rs. 32, 104.28)**
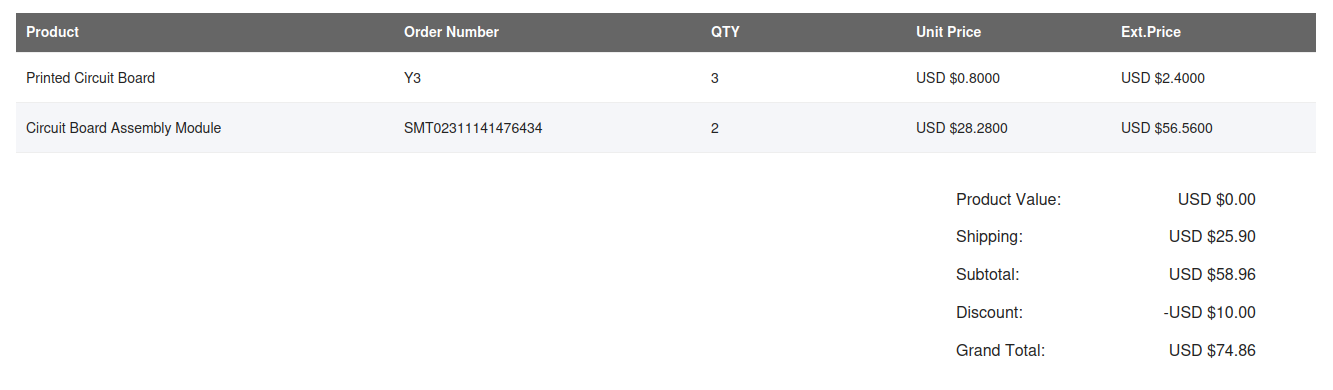
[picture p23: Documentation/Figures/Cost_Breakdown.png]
Cost Details
> 
> Order details

## Bill of Material
### 10uF Capacitors - Quantity 4
These are mostly used in the PCB for voltage filtering. It is not important to have the exact values but 10uF would be the ideal value for these capacitors.
- Components: C1, C2, C4, C5
- Brand/Model: Yageo CC0805KKX5R6BB106
- Description: 10V 10uF X5R ±10% 0805 Multilayer Ceramic Capacitors MLCC - SMD/SMT ROHS
- Datasheet: [10V 10uF X5R ±10% 0805 Multilayer Ceramic Capacitors MLCC - SMD/SMT ROHS](<10V 10uF X5R ±10% 0805 Multilayer Ceramic Capacitors MLCC - SMD/SMT ROHS>)
- JLCPCB: [https://jlcpcb.com/partdetail/Yageo-CC0805KKX5R6BB106/C89832](<## https://jlcpcb.com/partdetail/Yageo-CC0805KKX5R6BB106/C89832>)

### 0\.1uF Capacitors - Quantity 2
These are recommended components to be used in the ADC. Refer to its datasheet for the layout.
- Components: C3, C6
- Brand/Model: Yageo CC0805ZRY5V8BB104
- Description: 25V 100nF Y5V -20%\~+80% 0805 Multilayer Ceramic Capacitors MLCC - SMD/SMT ROHS
- Datasheet: [https://datasheet.lcsc.com/lcsc/2008171233\_YAGEO-CC0805ZRY5V8BB104\_C519930.pdf](<## https://datasheet.lcsc.com/lcsc/2008171233_YAGEO-CC0805ZRY5V8BB104_C519930.pdf>)
- JLCPCB: [https://jlcpcb.com/partdetail/Yageo-CC0805ZRY5V8BB104/C519930](<https://jlcpcb.com/partdetail/Yageo-CC0805ZRY5V8BB104/C519930>)

### 10kΩ Resistors - Quantity 7
These are used for pull-down purposes at the gate of MOSFETS. This is an ideal value for this application.
- Components: R3, R7, R11, R12, R14, R17, R21
- Brand/Model: Yageo AC0805JR-0710KL
- Description: 125mW Thick Film Resistors ±100ppm/℃ ±5% 10kΩ 0805 Chip Resistor - Surface Mount ROHS
- Datasheet: [https://datasheet.lcsc.com/lcsc/2304140030\_YAGEO-AC0805JR-0710KL\_C138260.pdf](<## https://datasheet.lcsc.com/lcsc/2304140030_YAGEO-AC0805JR-0710KL_C138260.pdf>)
- JLCPCB: [https://jlcpcb.com/partdetail/Yageo-AC0805JR0710KL/C138260](<https://jlcpcb.com/partdetail/Yageo-AC0805JR0710KL/C138260>)

### 100Ω Resistors - Quantity 5
These are used to drive the gate of MOSFETS. This is an ideal value for this application.
- Components: R9, R10, R13, R16, R19
- Brand/Model: Yageo AC0805JR-7W100RL
- Description: 250mW Thick Film Resistors ±100ppm/℃ ±5% 100Ω 0805 Chip Resistor - Surface Mount ROHS
- Datasheet: [https://datasheet.lcsc.com/lcsc/2304140030\_YAGEO-AC0805JR-7W100RL\_C728002.pdf](<## https://datasheet.lcsc.com/lcsc/2304140030_YAGEO-AC0805JR-7W100RL_C728002.pdf>)
- JLCPCB: [https://jlcpcb.com/partdetail/Yageo-AC0805JR7W100RL/C728002](<https://jlcpcb.com/partdetail/Yageo-AC0805JR7W100RL/C728002>)

### 220Ω Resistors - Quantity 2
These are used to drive the 5V source of MOSFETS. This is an ideal value for this application.
- Components: R15, R18
- Brand/Model: Panasonic ERJ6ENF2200V
- Description: 125mW Thick Film Resistors ±100ppm/℃ ±1% 220Ω 0805 Chip Resistor - Surface Mount ROHS
- Datasheet: [https://jlcpcb.com/c27a378e-b8d6-4204-a609-b03341428117](<https://jlcpcb.com/c27a378e-b8d6-4204-a609-b03341428117>)
- JLCPCB: [https://jlcpcb.com/partdetail/Panasonic-ERJ6ENF2200V/C413269](<## https://jlcpcb.com/partdetail/Panasonic-ERJ6ENF2200V/C413269>)

### 20kΩ Resistors - Quantity 1
This is an optional component used in case the ADC doesn't work.
- Components: R4
- Brand/Model: Yageo RC0805FR-0720KL
- Description: 125mW Thick Film Resistors ±100ppm/℃ ±1% 20kΩ 0805 Chip Resistor - Surface Mount ROHS
- Datasheet: [https://datasheet.lcsc.com/lcsc/2304140030\_YAGEO-RC0805FR-0720KL\_C114566.pdf](<## https://datasheet.lcsc.com/lcsc/2304140030_YAGEO-RC0805FR-0720KL_C114566.pdf>)
- JLCPCB: [https://jlcpcb.com/partdetail/Yageo-RC0805FR0720KL/C114566](<https://jlcpcb.com/partdetail/Yageo-RC0805FR0720KL/C114566>)

### 2kΩ Resistors - Quantity 1
These are recommended components to be used in the ADC. Refer to its datasheet for the layout.
- Components: R8
- Brand/Model: Panasonic ERJ6GEYJ202V
- Description: 125mW Thick Film Resistors ±5% ±200ppm/℃ 2000Ω 0805 Chip Resistor - Surface Mount ROHS
- Datasheet: [https://datasheet.lcsc.com/lcsc/1912111437\_PANASONIC-ERJ6GEYJ202V\_C413188.pdf](<## https://datasheet.lcsc.com/lcsc/1912111437_PANASONIC-ERJ6GEYJ202V_C413188.pdf>)
- JLCPCB: [https://jlcpcb.com/partdetail/Panasonic-ERJ6GEYJ202V/C413188](<https://jlcpcb.com/partdetail/Panasonic-ERJ6GEYJ202V/C413188>)

### 1N4001 Diode - Quantity 1
Used to protect the circuit from the back EMF of the relay.
- Components: D1
- Brand/Model: Vishay Intertech 1N4001-E3/73
- Description: 1A 50V 1.1V@1A DO-41 Diodes - General Purpose ROHS
- Datasheet: [https://datasheet.lcsc.com/lcsc/1912111437\_Vishay-Intertech-1N4001-E3-73\_C145491.pdf](<## https://datasheet.lcsc.com/lcsc/1912111437_Vishay-Intertech-1N4001-E3-73_C145491.pdf>)
- JLCPCB: [https://jlcpcb.com/partdetail/VishayIntertech-1N4001\_E373/C145491](<https://jlcpcb.com/partdetail/VishayIntertech-1N4001_E373/C145491>)

### Through Hole LED - Quantity 1
LM7805 Voltage RegulatorUsed as the primary LED indicator.
- Components: D2
- Brand/Model: Everlight Electric 333-2SURD/S530-A3-L
- Description: Red Plugin,D=5mm Light Emitting Diodes (LED) ROHS
- Datasheet: [https://datasheet.lcsc.com/lcsc/1810231815\_Everlight-Elec-333-2SURD-S530-A3-L\_C99758.pdf](<https://datasheet.lcsc.com/lcsc/1810231815_Everlight-Elec-333-2SURD-S530-A3-L_C99758.pdf>)
- JLCPCB: [https://jlcpcb.com/partdetail/EverlightElec-333\_2SURD\_S530\_A3L/C99758](<## https://jlcpcb.com/partdetail/EverlightElec-333_2SURD_S530_A3L/C99758>)

### LMS1585 Voltage Regulator - Quantity 1
Used to step down the 12V supply down to 3.3V for the development kit.
- Components: U1
- Brand/Model: Texas Instruments LMS1585ACT-3.3/NOPB
- Description: 72dB@(120Hz) 5A Fixed 3.3V Positive 13V TO-220 Linear Voltage Regulators (LDO) ROHS
- Datasheet: [https://datasheet.lcsc.com/lcsc/1806121225\_Texas-Instruments-LMS1585ACT-3-3-NOPB\_C140341.pdf](<https://datasheet.lcsc.com/lcsc/1806121225_Texas-Instruments-LMS1585ACT-3-3-NOPB_C140341.pdf>)
- JLCPCB: [https://jlcpcb.com/partdetail/TexasInstruments-LMS1585ACT\_3\_3NOPB/C140341](<## https://jlcpcb.com/partdetail/TexasInstruments-LMS1585ACT_3_3NOPB/C140341>)

### LM7805 Voltage Regulator - Quantity 1
Used to step down the 12V supply down to 5V for the sensors/indicators.
- Components: U2
- Brand/Model: Shanghai Siproin Microelectronics LM7805CT
- Description: 1.5A null 5V positive 35V TO-220 Linear Voltage Regulators (LDO) ROHS
- Datasheet: [https://datasheet.lcsc.com/lcsc/2304120930\_Shanghai-Siproin-Microelectronics-LM7805CT\_C5444281.pdf](<https://datasheet.lcsc.com/lcsc/2304120930_Shanghai-Siproin-Microelectronics-LM7805CT_C5444281.pdf>)
- JLCPCB: [https://jlcpcb.com/partdetail/6334298-LM7805CT/C5444281](<## https://jlcpcb.com/partdetail/6334298-LM7805CT/C5444281>)

### XD549 ADC - Quantity 1
Used to step down the 12V supply down to 5V for the sensors/indicators.
- Components: U3
- Brand/Model: XINLUDA XD549
- Description: DIP-8 Analog To Digital Converters (ADCs) ROHS
- Datasheet: [https://datasheet.lcsc.com/lcsc/2007301834\_XINLUDA-XD549\_C707061.pdf](<https://datasheet.lcsc.com/lcsc/2007301834_XINLUDA-XD549_C707061.pdf>)
- JLCPCB: [https://jlcpcb.com/partdetail/XINLUDA-XD549/C707061](<https://jlcpcb.com/partdetail/XINLUDA-XD549/C707061>)

### MQ-135 Gas Sensor - Quantity 1
Used to detect the presence of CO2 gas.
- Components: U4
- Brand/Model: -- MQ-135
- Description: 2.5V to 5.0V, 150mA, NH3, Nox, CO2, Alcohol, Benzene, Smoke,
- Datasheet: [https://pdf1.alldatasheet.com/datasheet-pdf/download/1307647/WINSEN/MQ135.html](<https://pdf1.alldatasheet.com/datasheet-pdf/download/1307647/WINSEN/MQ135.html>)
- JLCPCB: --

### DHT-11 Temperature/Humidity Sensor - Quantity 1
Used to detect the temperature and humidity.
- Components: U5
- Brand/Model: -- DHT-11
- Description: 3 to 5V DC, 20-80% humidity; ±5% accuracy, -20°C to 50°C temperature; ±2°C accuracy
- Datasheet: [https://components101.com/sites/default/files/component\_datasheet/DHT11-Temperature-Sensor.pdf](<https://components101.com/sites/default/files/component_datasheet/DHT11-Temperature-Sensor.pdf>)
- JLCPCB: --

### IRLML 6246 MOSFET - Quantity 3
Used for controlling digital output devices.
- Components: Q1, Q2, Q3
- Brand/Model: Infineon Technologies IRLML6246TRPBF
- Description: 20V 4.1A 1.3W 46mΩ@4.5V,4.1A N Channel SOT-23 MOSFETs ROHS
- Datasheet: [https://datasheet.lcsc.com/lcsc/1810181614\_Infineon-Technologies-IRLML6246TRPBF\_C82053.pdf](<https://datasheet.lcsc.com/lcsc/1810181614_Infineon-Technologies-IRLML6246TRPBF_C82053.pdf>)
- JLCPCB: [https://jlcpcb.com/partdetail/InfineonTechnologies-IRLML6246TRPBF/C82053](<https://jlcpcb.com/partdetail/InfineonTechnologies-IRLML6246TRPBF/C82053>)

### TXS0108EQ Level Shifter - Quantity 1
The nRF works with 3.3V while most IO devices operate in 5V. TXS0108 allows to bridge this voltage gap.
- Components: IC1
- Brand/Model: Texas Instruments TXS0108EQPWRQ1
- Description: 1.65V\~5.5V 8 110Mbps 1.4V\~3.6V TSSOP-20 Translators / Level Shifters ROHS
- Datasheet: [http://www.ti.com/lit/gpn/txs0108e-q1](<http://www.ti.com/lit/gpn/txs0108e-q1>)
- JLCPCB: [https://jlcpcb.com/partdetail/TexasInstruments-TXS0108EQPWRQ1/C1021790](<https://jlcpcb.com/partdetail/TexasInstruments-TXS0108EQPWRQ1/C1021790>)

### SRD-05 Relay - Quantity 1
Relay to control the valve.
- Components: K1
- Brand/Model: HF(Xiamen Hongfa Electroacoustic) HF3FF/005-1ZTF
- Description: AgSnO2 5V SPDT (1 Form C) 5 Plugin,15.2x19mm Power Relays ROHS
- Datasheet: [https://jlcpcb.com/648054f8-0a52-4422-91d4-b47ff4728931](<https://jlcpcb.com/648054f8-0a52-4422-91d4-b47ff4728931>)
- JLCPCB: [https://jlcpcb.com/partdetail/2900301-HF3FF\_0051ZTF/C2764967](<https://jlcpcb.com/partdetail/2900301-HF3FF_0051ZTF/C2764967>)

### CPE-222H Buzzer - Quantity 1
Buzzer indicator.
- Components: LS1
- Brand/Model: Jiangsu Huaneng Electric HMB1206-05
- Description: Active (driven circuit included) 85dB@5V,10cm Magnetic 2600Hz Plugin,D=12mm Buzzers ROHS
- Datasheet: [https://datasheet.lcsc.com/lcsc/1811141116\_Jiangsu-Huaneng-Elec-HMB1206-05\_C96095.pdf](<https://datasheet.lcsc.com/lcsc/1811141116_Jiangsu-Huaneng-Elec-HMB1206-05_C96095.pdf>)
- JLCPCB: [https://jlcpcb.com/partdetail/Jiangsu\_HuanengElec-HMB120605/C96095](<https://jlcpcb.com/partdetail/Jiangsu_HuanengElec-HMB120605/C96095>)

### DTS-62 Vertical Switch - Quantity 1
Buzzer indicator.
- Components: S1
- Brand/Model: Jiangsu Huaneng Electric HMB1206-05
- Description: Active (driven circuit included) 85dB@5V,10cm Magnetic 2600Hz Plugin,D=12mm Buzzers ROHS
- Datasheet: [https://jlcpcb.com/0b519b37-43cc-45d3-a61c-acdea244da25](<https://jlcpcb.com/0b519b37-43cc-45d3-a61c-acdea244da25>)
- JLCPCB: [https://jlcpcb.com/partdetail/Diptronics-DTS\_65YV/C141879](<https://jlcpcb.com/partdetail/Diptronics-DTS_65YV/C141879>)

### XKB DC-005 Barrel Jack Connector - Quantity 1
5V DC connector for input power.
- Components: J1
- Brand/Model: XKB Connectivity DC-005-5A-2.0
- Description: DC Power Receptacle 260℃ Brass -20℃\~+70℃ 2mm 6.2mm 5A 24V Plugin AC/DC Power Connectors
- Datasheet: [https://jlcpcb.com/dd7b5382-57f0-4ae1-9886-7141703030e4](<https://jlcpcb.com/dd7b5382-57f0-4ae1-9886-7141703030e4>)
- JLCPCB: [https://jlcpcb.com/partdetail/XkbConnectivity-DC\_005\_5A\_20/C381116](<https://jlcpcb.com/partdetail/XkbConnectivity-DC_005_5A_20/C381116>)

### 2x1 Molex Connector - Quantity 1
Standard 2x1 molex connector output to the valve.
- Components: J2
- Brand/Model: -
- Description: -
- Datasheet: -
- JLCPCB: -

### 1x13 Pin Header - Quantity 1
Standard 2x13, 2.5mm pin header for IO with nRF7002 DK.
- Components: J3
- Brand/Model: -
- Description: -
- Datasheet: -
- JLCPCB: -

### nRF 7002 DK Development Board - Quantity 1
The nRF 7002 DK for control.
- Components: -
- Brand/Model: Nordic Semiconductors nRF7002 DK
- Description: -
- Datasheet: [https://infocenter.nordicsemi.com/topic/ug\_nrf7002\_dk/UG/nrf7002\_DK/intro.html](<https://infocenter.nordicsemi.com/topic/ug_nrf7002_dk/UG/nrf7002_DK/intro.html>)
- Manufacturer - [https://www.nordicsemi.com/Products/Development-hardware/nRF7002-DK](<https://www.nordicsemi.com/Products/Development-hardware/nRF7002-DK>)

### 12V Power Supply with DC Barel Jack - Quantity 1
12V DC power supply with a DC barrel jack. Any power supply would do at a minimum of 500mA of supply current.
- Components: -
- Brand/Model: -
- Description: -
- Datasheet: -
- JLCPCB: -

### Micro USB Cable - Quantity 1
Any micro USB cable that can connect to the nRF 7002 DK would do.
- Components: -
- Brand/Model: -
- Description: -
- Datasheet: -
- JLCPCB: -

### 1x13 Male to Female Ribbon Cable - Quantity 1
Cable used to connect the IO of nRF7002 DK to the Prometheus PCB v2.0.
- Components: -
- Brand/Model: -
- Description: -
- Datasheet: -
- JLCPCB: -

### ZE-4F180 Valve with compatible tubing and spray end - Quantity 1
Any valve that supports 12V operation with normally closed configuration would to. Other components are required only to setup the sprinkler system.
- Components: -
- Brand/Model: -
- Description: -
- Datasheet: -
- JLCPCB: -

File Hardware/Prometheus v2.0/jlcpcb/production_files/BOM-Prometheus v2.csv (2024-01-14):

Comment | Designator | Footprint | LCSC
TXS0108EQPWRQ1 | IC1 | SOP65P640X120-20N | C1021790
20k | R4 | R_0805_2012Metric | C114566
10k | R11,R12,R14,R17,R21,R3,R7 | R_0805_2012Metric | C138260
LMS1585ACT-3.3_NOPB | U1 | TO254P470X1028X1955-3P | C140341
1N4001 | D1 | D_DO-41_SOD81_P10.16mm_Horizontal | C145491
DTS-62N-V | S1 | DTS62NV | C224975
220R | R15,R18 | R_0805_2012Metric | C340559
DC-005-5A-2.0 | J1 | XKB_DC-005-5A-2.0 | C381116
2k | R8 | R_0805_2012Metric | C413188
0.1uF | C3,C6 | C_0805_2012Metric | C519930
LM7805_TO220 | U2 | TO-220-3_Vertical | C5444281
XD549 | U3 | DIP-8_W7.62mm | C707061
100R | R10,R13,R16,R19,R9 | R_0805_2012Metric | C728002
IRLML6246 | Q1,Q2,Q3 | SOT-23 | C82053
10uF | C1,C2,C4,C5 | C_0805_2012Metric | C89832
CPE-222H | LS1 | MagneticBuzzer_StarMicronics_HMB-06_HMB-12 | C96095
SRD-05VDC-SL-C | K1 | RELAY_SRD-05VDC-SL-C | C99666
LED | D2 | LED_D3.0mm_FlatTop | C99758
MQ_135_D_TP | TP13 | TestPoint_Pad_1.0x1.0mm
LED_TP | TP15 | TestPoint_Pad_1.0x1.0mm
MountingHole | H4 | MountingHole_2.5mm_Pad_TopBottom
MQ_135_5V_TP | TP12 | TestPoint_Pad_1.0x1.0mm
VREF_A_TP | TP3 | TestPoint_Pad_1.0x1.0mm
DHT_11_3V3_TP | TP20 | TestPoint_Pad_1.0x1.0mm
DNP | R20 | R_0805_2012Metric
GND_TP | TP25 | TestPoint_Pad_2.0x2.0mm
DNP | R2 | R_0805_2012Metric
MQ_135_D_3V3_TP | TP24 | TestPoint_Pad_1.0x1.0mm
MQ_135_SCL_TP | TP7 | TestPoint_Pad_1.0x1.0mm
Indicator_LED_3V3_TP | TP19 | TestPoint_Pad_1.0x1.0mm
LS_EN_TP | TP6 | TestPoint_Pad_1.0x1.0mm
DNP | R1 | R_0805_2012Metric
12V_TP | TP1 | TestPoint_Pad_1.0x1.0mm
Solenoid_Control_3V3_TP | TP17 | TestPoint_Pad_1.0x1.0mm
Solenoid_Out_TP | TP14 | TestPoint_Pad_1.0x1.0mm
Buzzer_TP | TP16 | TestPoint_Pad_1.0x1.0mm
MQ_135_SDA_TP | TP11 | TestPoint_Pad_1.0x1.0mm
5V_TP | TP4 | TestPoint_Pad_1.0x1.0mm
Reset_TP | TP27 | TestPoint_Pad_1.0x1.0mm
MQ_135_SDA_3V3_TP | TP21 | TestPoint_Pad_1.0x1.0mm
MountingHole | H3 | MountingHole_2.5mm_Pad_TopBottom
Solenoid_In_TP | TP10 | TestPoint_Pad_1.0x1.0mm
DHT_11_TP | TP26 | TestPoint_Pad_1.0x1.0mm
DNP | R6 | R_0805_2012Metric
Conn_01x13_Pin | J3 | PinHeader_1x13_P2.54mm_Vertical
MountingHole | H2 | MountingHole_2.5mm_Pad_TopBottom
Conn_01x02_Socket | J2 | Molex_Mega-Fit_76825-0002_2x01_P5.70mm_Horizontal
MountingHole | H1 | MountingHole_2.5mm_Pad_TopBottom
Indicator_Buzzer_3V3_TP | TP18 | TestPoint_Pad_1.0x1.0mm
MQ_135_SCL_3V3_TP | TP22 | TestPoint_Pad_1.0x1.0mm
DNP | R5 | R_0805_2012Metric
MQ_135_CS_3V3_TP | TP23 | TestPoint_Pad_1.0x1.0mm
MQ_135_A_3V3_TP | TP2 | TestPoint_Pad_1.0x1.0mm
3V3_TP | TP5 | TestPoint_Pad_1.0x1.0mm
MQ_135_CS_TP | TP8 | TestPoint_Pad_1.0x1.0mm
VREF_B_TP | TP9 | TestPoint_Pad_1.0x1.0mm
DHT-11 | U5 | DHT-11
MQ-135 | U4 | MQ-135

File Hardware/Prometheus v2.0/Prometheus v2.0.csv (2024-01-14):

# | Reference | Qty | Value | Footprint | DNP
1 | C1, C2, C4, C5 | 4 | 10uF | Capacitor_SMD:C_0805_2012Metric
2 | C3, C6 | 2 | 0.1uF | Capacitor_SMD:C_0805_2012Metric
3 | D1 | 1 | 1N4001 | Diode_THT:D_DO-41_SOD81_P10.16mm_Horizontal
4 | D2 | 1 | LED | LED_THT:LED_D3.0mm_FlatTop
5 | H1, H2, H3, H4 | 4 | MountingHole | MountingHole:MountingHole_2.5mm_Pad_TopBottom
6 | IC1 | 1 | TXS0108EQPWRQ1 | TXS0108EQPWRQ1:SOP65P640X120-20N
7 | J1 | 1 | DC-005-5A-2.0 | Connectors:XKB_DC-005-5A-2.0
8 | J2 | 1 | Conn_01x02_Socket | Connector_Molex:Molex_Mega-Fit_76825-0002_2x01_P5.70mm_Horizontal
9 | J3 | 1 | Conn_01x13_Pin | Connector_PinHeader_2.54mm:PinHeader_1x13_P2.54mm_Vertical
10 | K1 | 1 | SRD-05VDC-SL-C | SRD-05VDC-SL-C:RELAY_SRD-05VDC-SL-C
11 | LS1 | 1 | CPE-222H | Buzzer_Beeper:MagneticBuzzer_StarMicronics_HMB-06_HMB-12
12 | Q1, Q2, Q3 | 3 | IRLML6246 | Package_TO_SOT_SMD:SOT-23
13 | R1, R2, R5, R6, R20 | 5 | DNP | Resistor_SMD:R_0805_2012Metric
14 | R3, R7, R11, R12, R14, R17, R21 | 7 | 10k | Resistor_SMD:R_0805_2012Metric
15 | R4 | 1 | 20k | Resistor_SMD:R_0805_2012Metric
16 | R8 | 1 | 2k | Resistor_SMD:R_0805_2012Metric
17 | R9, R10, R13, R16, R19 | 5 | 100R | Resistor_SMD:R_0805_2012Metric
18 | R15, R18 | 2 | 220R | Resistor_SMD:R_0805_2012Metric
19 | S1 | 1 | DTS-62N-V | DTS-62N-V:DTS62NV
20 | TP1 | 1 | 12V_TP | TestPoint:TestPoint_Pad_1.0x1.0mm
21 | TP2 | 1 | MQ_135_A_3V3_TP | TestPoint:TestPoint_Pad_1.0x1.0mm
22 | TP3 | 1 | VREF_A_TP | TestPoint:TestPoint_Pad_1.0x1.0mm
23 | TP4 | 1 | 5V_TP | TestPoint:TestPoint_Pad_1.0x1.0mm
24 | TP5 | 1 | 3V3_TP | TestPoint:TestPoint_Pad_1.0x1.0mm
25 | TP6 | 1 | LS_EN_TP | TestPoint:TestPoint_Pad_1.0x1.0mm
26 | TP7 | 1 | MQ_135_SCL_TP | TestPoint:TestPoint_Pad_1.0x1.0mm
27 | TP8 | 1 | MQ_135_CS_TP | TestPoint:TestPoint_Pad_1.0x1.0mm
28 | TP9 | 1 | VREF_B_TP | TestPoint:TestPoint_Pad_1.0x1.0mm
29 | TP10 | 1 | Solenoid_In_TP | TestPoint:TestPoint_Pad_1.0x1.0mm
30 | TP11 | 1 | MQ_135_SDA_TP | TestPoint:TestPoint_Pad_1.0x1.0mm
31 | TP12 | 1 | MQ_135_5V_TP | TestPoint:TestPoint_Pad_1.0x1.0mm
32 | TP13 | 1 | MQ_135_D_TP | TestPoint:TestPoint_Pad_1.0x1.0mm
33 | TP14 | 1 | Solenoid_Out_TP | TestPoint:TestPoint_Pad_1.0x1.0mm
34 | TP15 | 1 | LED_TP | TestPoint:TestPoint_Pad_1.0x1.0mm
35 | TP16 | 1 | Buzzer_TP | TestPoint:TestPoint_Pad_1.0x1.0mm
36 | TP17 | 1 | Solenoid_Control_3V3_TP | TestPoint:TestPoint_Pad_1.0x1.0mm
37 | TP18 | 1 | Indicator_Buzzer_3V3_TP | TestPoint:TestPoint_Pad_1.0x1.0mm
38 | TP19 | 1 | Indicator_LED_3V3_TP | TestPoint:TestPoint_Pad_1.0x1.0mm
39 | TP20 | 1 | DHT_11_3V3_TP | TestPoint:TestPoint_Pad_1.0x1.0mm
40 | TP21 | 1 | MQ_135_SDA_3V3_TP | TestPoint:TestPoint_Pad_1.0x1.0mm
41 | TP22 | 1 | MQ_135_SCL_3V3_TP | TestPoint:TestPoint_Pad_1.0x1.0mm
42 | TP23 | 1 | MQ_135_CS_3V3_TP | TestPoint:TestPoint_Pad_1.0x1.0mm
43 | TP24 | 1 | MQ_135_D_3V3_TP | TestPoint:TestPoint_Pad_1.0x1.0mm
44 | TP25 | 1 | GND_TP | TestPoint:TestPoint_Pad_2.0x2.0mm
45 | TP26 | 1 | DHT_11_TP | TestPoint:TestPoint_Pad_1.0x1.0mm
46 | TP27 | 1 | Reset_TP | TestPoint:TestPoint_Pad_1.0x1.0mm
47 | U1 | 1 | LMS1585ACT-3.3_NOPB | LMS1585ACT-3.3_NOPB:TO254P470X1028X1955-3P
48 | U2 | 1 | LM7805_TO220 | Package_TO_SOT_THT:TO-220-3_Vertical
49 | U3 | 1 | XD549 | Package_DIP:DIP-8_W7.62mm
50 | U4 | 1 | MQ-135 | Sensors:MQ-135
51 | U5 | 1 | DHT-11 | Sensors:DHT-11

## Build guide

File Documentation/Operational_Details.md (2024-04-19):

# Operational Details
This section will introduce the basic operational details of the Prometheus Fire Alarm System v2.0. It will cover topics of [Operational Architecture](< # Operational Architecture >), [Features and Advantages of the System](< # Features and Advantages of the System >), [Technical Limitations](< # Technical Limitations >) and [Communication Architecture](< # Communication Architecture >).

For comprehensive introduction about the hardware architecture, refer to the Hardware Architecture section. Likewise, refer to the Software Architecture of a comprehensive introduction to the Software Architecture.

# Operational Architecture
This fire alarm system is designed to detect, indicate and extinguish fire by using necessary precautions. The system is expected to consist of three main stages.

1. Fire sensing and extinguishing system
2. Control stage
3. Alarming and notification stage

There are four main sections and components for the proper functioning of the system. It will help to complete that all the stages that mentioned above.

1. Fire sensors
2. Extinguishing valves
3. Control unit
4. Software system
5. Structural design

The system is designed to support as many of the Fire Alarm Modules as required according to the implemented environment. For example, if we are implementing in a school, each classroom can have individual modules. But accordingly, we will have to upgrade the control system used.

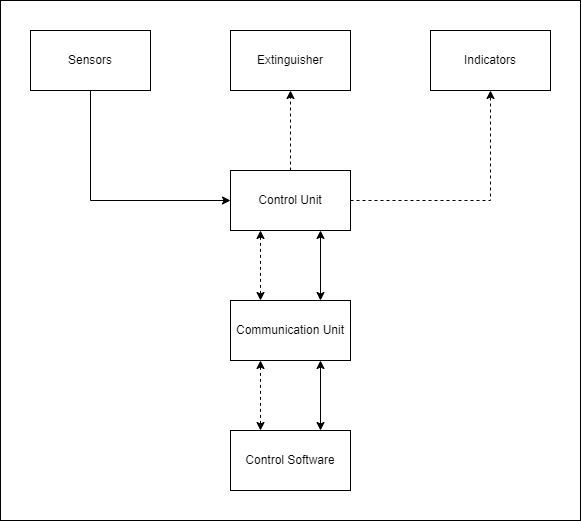
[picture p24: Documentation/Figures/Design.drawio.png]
Operational Structure
> 
>  Operational Structure

# Features and Advantages of the System
From a design standpoint, Prometheus Fire Alarm System v1.0 had a unique design philosophy that allowed it to be capable of evolving it into an IoT based fire alarm system. This is because a key importance was given to make it not just a monitoring and extinguishing device, but to go even further and become a user interactable and customizable system.

This is what was capitalized to integrate the Prometheus Fire Alarm System with the Matter protocol. For a comprehensive discussion on Matter and Prometheus Fire Alarm System, refer to [Project Management](./Project_Management.md) section. Some features and advantages will be discussed below.

- Real-time monitoring of the environment
- Real-time detection and reaction system
- Complete operation done within the system itself without offloading (Safer and more reliable operation)
- Real-time stats can be accessed via the control panel/matter home network
- Flexibility to integrate newer communication systems to increase functionality
- Fully open-sourced hardware and software architecture allowing transparency and learning opportunities

# Technical Limitations
Above advantages does come with some limitations. Everything was done by myself alone in my spare time juggling both work, studies and my personal life. With the limited time and budget available, I am proud of what I've achieved. However, it is important to acknowledge the limitations that currently exist in the developed system.

- Incomplete Matter integration
- No method to handle power loss
- No checks in place to indicate if water line goes dry
- Existing communication system, though robust, is limited and inefficient
- nRF kit is not integrated into a single PCB solution
- Slight issues with the PCB layout of the Prometheus PCB

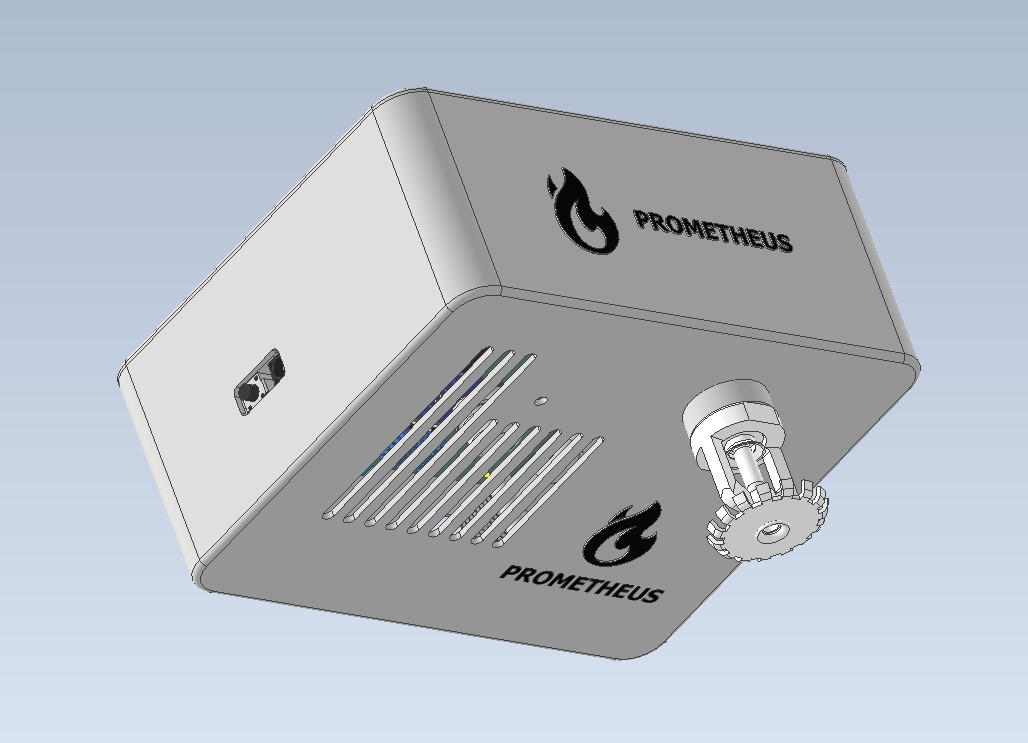
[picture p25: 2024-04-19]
Enclosure/Assembly_View_02.jpeg

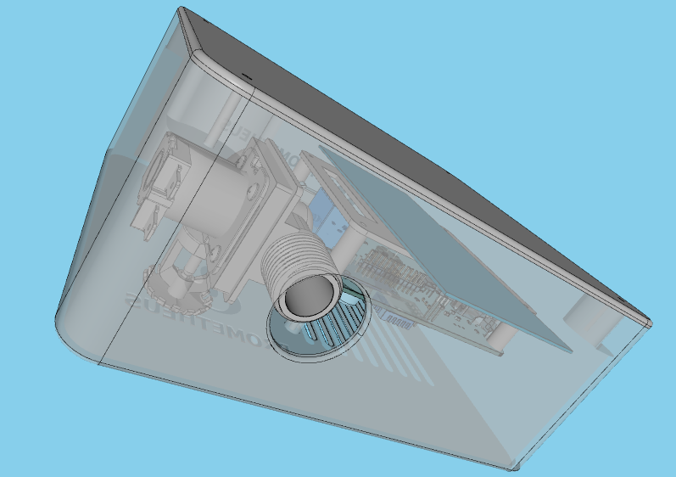
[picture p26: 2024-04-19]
Enclosure/Assembly_View_06.png

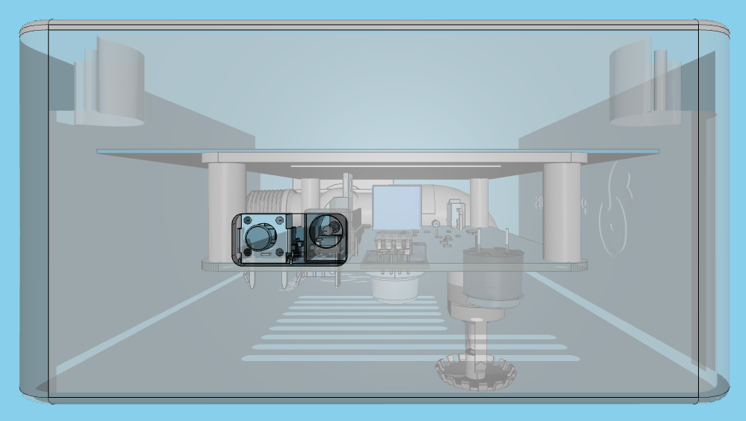
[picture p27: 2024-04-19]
Enclosure/Assembly_View_10.png

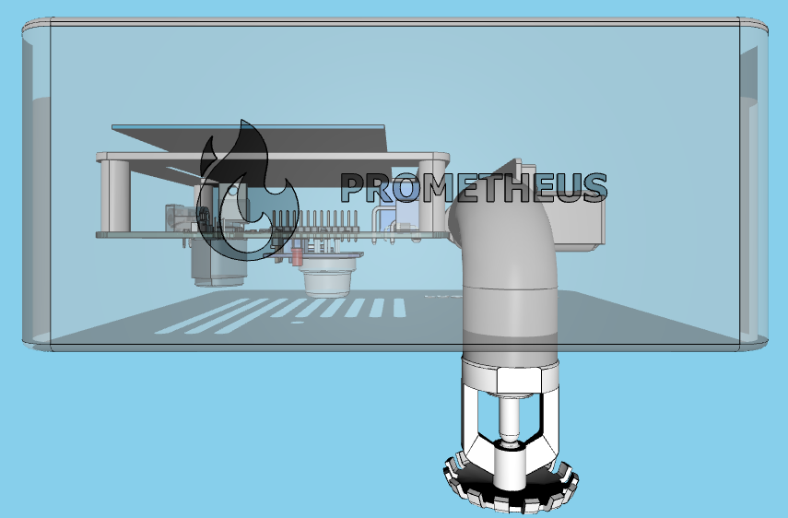
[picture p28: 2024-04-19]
Enclosure/Assembly_View_09.png

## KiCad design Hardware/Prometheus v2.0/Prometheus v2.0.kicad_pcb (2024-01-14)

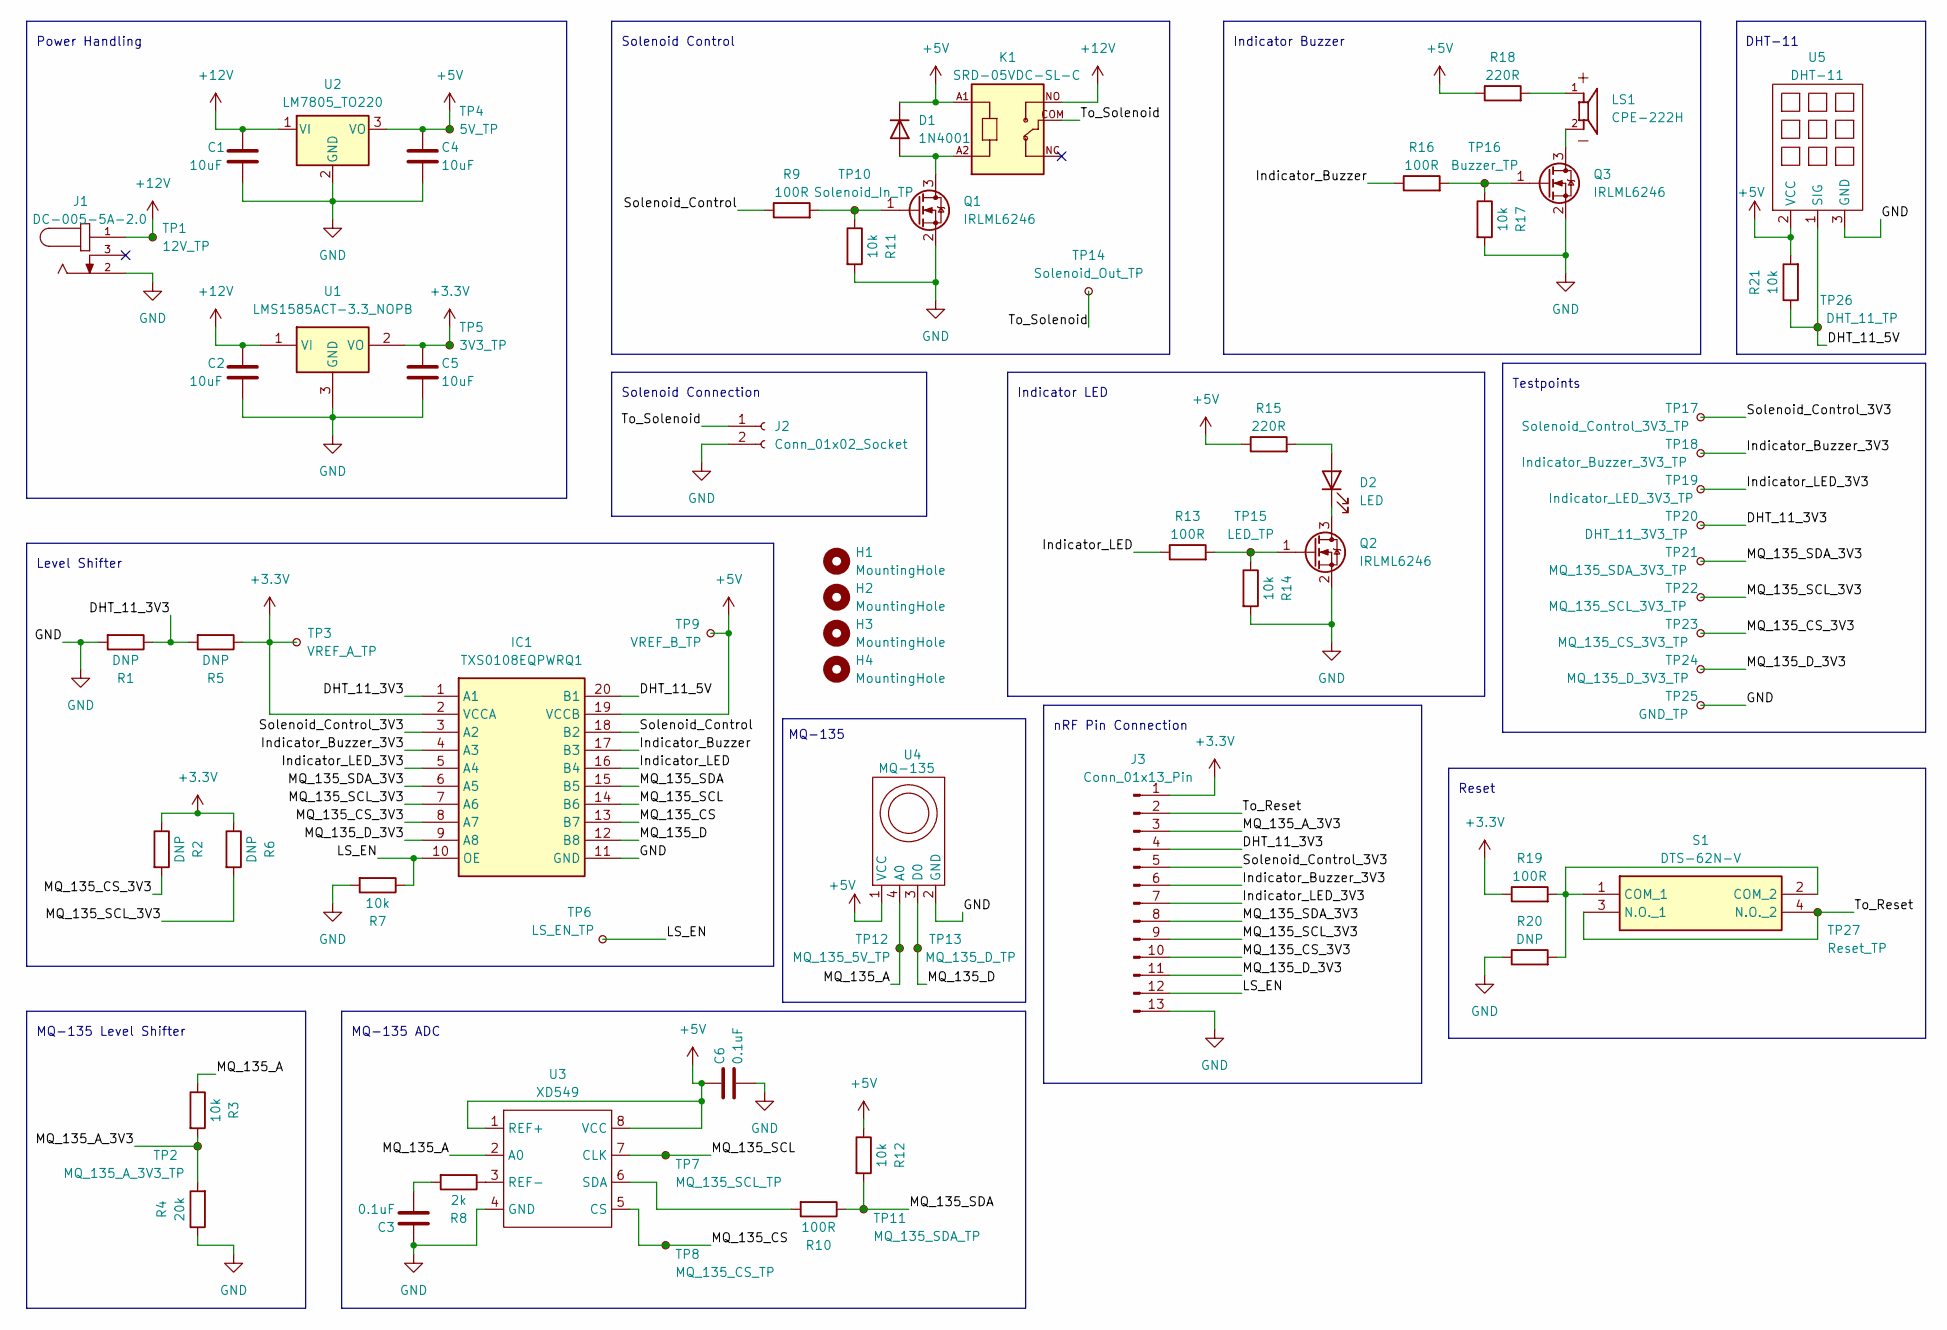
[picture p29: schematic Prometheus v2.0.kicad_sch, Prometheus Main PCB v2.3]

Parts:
C1, C2, C4, C5: 10uF; C_0805_2012Metric
C3, C6: 0.1uF; C_0805_2012Metric
D1: 1N4001; D_DO-41_SOD81_P10.16mm_Horizontal
D2: LED; LED_D3.0mm_FlatTop
H1, H2, H3, H4: MountingHole; MountingHole_2.5mm_Pad_TopBottom
IC1: TXS0108EQPWRQ1; SOP65P640X120-20N; Mouser Part Number 595-TXS0108EQPWRQ1
J1: DC-005-5A-2.0; XKB_DC-005-5A-2.0; PARTREV A0
J2: Conn_01x02_Socket; Molex_Mega-Fit_76825-0002_2x01_P5.70mm_Horizontal
J3: Conn_01x13_Pin; PinHeader_1x13_P2.54mm_Vertical
K1: SRD-05VDC-SL-C; RELAY_SRD-05VDC-SL-C
LS1: CPE-222H; MagneticBuzzer_StarMicronics_HMB-06_HMB-12
Q1, Q2, Q3: IRLML6246; SOT-23
R1, R2, R5, R6, R20: DNP; R_0805_2012Metric
R3, R7, R11, R12, R14, R17, R21: 10k; R_0805_2012Metric
R4: 20k; R_0805_2012Metric
R8: 2k; R_0805_2012Metric
R9, R10, R13, R16, R19: 100R; R_0805_2012Metric
R15, R18: 220R; R_0805_2012Metric
S1: DTS-62N-V; DTS62NV; Mouser Part Number 113-DTS-62N-V
TP1: 12V_TP; TestPoint_Pad_1.0x1.0mm
TP2: MQ_135_A_3V3_TP; TestPoint_Pad_1.0x1.0mm
TP3: VREF_A_TP; TestPoint_Pad_1.0x1.0mm
TP4: 5V_TP; TestPoint_Pad_1.0x1.0mm
TP5: 3V3_TP; TestPoint_Pad_1.0x1.0mm
TP6: LS_EN_TP; TestPoint_Pad_1.0x1.0mm
TP7: MQ_135_SCL_TP; TestPoint_Pad_1.0x1.0mm
TP8: MQ_135_CS_TP; TestPoint_Pad_1.0x1.0mm
TP9: VREF_B_TP; TestPoint_Pad_1.0x1.0mm
TP10: Solenoid_In_TP; TestPoint_Pad_1.0x1.0mm
TP11: MQ_135_SDA_TP; TestPoint_Pad_1.0x1.0mm
TP12: MQ_135_5V_TP; TestPoint_Pad_1.0x1.0mm
TP13: MQ_135_D_TP; TestPoint_Pad_1.0x1.0mm
TP14: Solenoid_Out_TP; TestPoint_Pad_1.0x1.0mm
TP15: LED_TP; TestPoint_Pad_1.0x1.0mm
TP16: Buzzer_TP; TestPoint_Pad_1.0x1.0mm
TP17: Solenoid_Control_3V3_TP; TestPoint_Pad_1.0x1.0mm
TP18: Indicator_Buzzer_3V3_TP; TestPoint_Pad_1.0x1.0mm
TP19: Indicator_LED_3V3_TP; TestPoint_Pad_1.0x1.0mm
TP20: DHT_11_3V3_TP; TestPoint_Pad_1.0x1.0mm
TP21: MQ_135_SDA_3V3_TP; TestPoint_Pad_1.0x1.0mm
TP22: MQ_135_SCL_3V3_TP; TestPoint_Pad_1.0x1.0mm
TP23: MQ_135_CS_3V3_TP; TestPoint_Pad_1.0x1.0mm
TP24: MQ_135_D_3V3_TP; TestPoint_Pad_1.0x1.0mm
TP25: GND_TP; TestPoint_Pad_2.0x2.0mm
TP26: DHT_11_TP; TestPoint_Pad_1.0x1.0mm
TP27: Reset_TP; TestPoint_Pad_1.0x1.0mm
U1: LMS1585ACT-3.3_NOPB; TO254P470X1028X1955-3P; Mouser Part Number 926-LMS1585ACT33NOPB
U2: LM7805_TO220; TO-220-3_Vertical
U3: XD549; DIP-8_W7.62mm
U4: MQ-135
U5: DHT-11

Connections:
+3.3V: C5.1, IC1.2 (VCCA), J3.1, R2.1, R5.1, R6.1, R19.1, TP3.1, TP5.1, U1.2 (VO)
+5V: C4.1, C6.1, D1.1 (K), IC1.19 (VCCB), K1.A1, R12.1, R15.1, R18.1, R21.2, TP4.1, TP9.1, U2.3 (VO), U3.1 (REF+), U3.8 (VCC), U4.1 (VCC), U5.2 (VCC)
+12V: C1.1, C2.1, J1.1, K1.NO, TP1.1, U1.1 (VI), U2.1 (VI)
/DHT_11_3V3: IC1.1 (A1), J3.4, R1.1, R5.2, TP20.1
/DHT_11_5V: IC1.20 (B1), R21.1, TP26.1, U5.1 (SIG)
/Indicator_Buzzer: IC1.17 (B3), R16.1
/Indicator_Buzzer_3V3: IC1.4 (A3), J3.6, TP18.1
/Indicator_LED: IC1.16 (B4), R13.1
/Indicator_LED_3V3: IC1.5 (A4), J3.7, TP19.1
/LS_EN: IC1.10 (OE), J3.12, R7.1, TP6.1
/MQ_135_A: R3.1, TP12.1, U3.2 (A0), U4.4 (A0)
/MQ_135_A_3V3: J3.3, R3.2, R4.2, TP2.1
/MQ_135_CS: IC1.13 (B7), TP8.1, U3.5 (CS)
/MQ_135_CS_3V3: IC1.8 (A7), J3.10, R2.2, TP23.1
/MQ_135_D: IC1.12 (B8), TP13.1, U4.3 (D0)
/MQ_135_D_3V3: IC1.9 (A8), J3.11, TP24.1
/MQ_135_SCL: IC1.14 (B6), TP7.1, U3.7 (CLK)
/MQ_135_SCL_3V3: IC1.7 (A6), J3.9, R6.2, TP22.1
/MQ_135_SDA: IC1.15 (B5), R10.1, R12.2, TP11.1
/MQ_135_SDA_3V3: IC1.6 (A5), J3.8, TP21.1
/Solenoid_Control: IC1.18 (B2), R9.1
/Solenoid_Control_3V3: IC1.3 (A2), J3.5, TP17.1
/To_Reset: J3.2, S1.3 (N.O._1), S1.4 (N.O._2), TP27.1
/To_Solenoid: J2.1, K1.COM, TP14.1
GND: C1.2, C2.2, C3.1, C4.2, C5.2, C6.2, IC1.11 (GND), J1.2, J2.2, J3.13, Q1.2 (S), Q2.2 (S), Q3.2 (S), R1.2, R4.1, R7.2, R11.2, R14.2, R17.2, R20.1, TP25.1, U1.3 (GND), U2.2 (GND), U3.4 (GND), U4.2 (GND), U5.3 (GND)
unnamed: C3.2, R8.2
unnamed: D1.2 (A), K1.A2, Q1.3 (D)
unnamed: D2.2 (A), R15.2
unnamed: D2.1 (K), Q2.3 (D)
unnamed: LS1.1, R18.2
unnamed: Q1.1 (G), R9.2, R11.1, TP10.1
unnamed: Q2.1 (G), R13.2, R14.1, TP15.1
unnamed: LS1.2, Q3.3 (D)
unnamed: Q3.1 (G), R16.2, R17.1, TP16.1
unnamed: R19.2, R20.2, S1.1 (COM_1), S1.2 (COM_2)
unnamed: R8.1, U3.3 (REF-)
unnamed: R10.2, U3.6 (SDA)

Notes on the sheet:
Testpoints
Power Handling
Solenoid Connection
Indicator LED
MQ-135
Indicator Buzzer
Level Shifter
Solenoid Control
DHT-11
nRF Pin Connection
MQ-135 ADC
MQ-135 Level Shifter
Reset

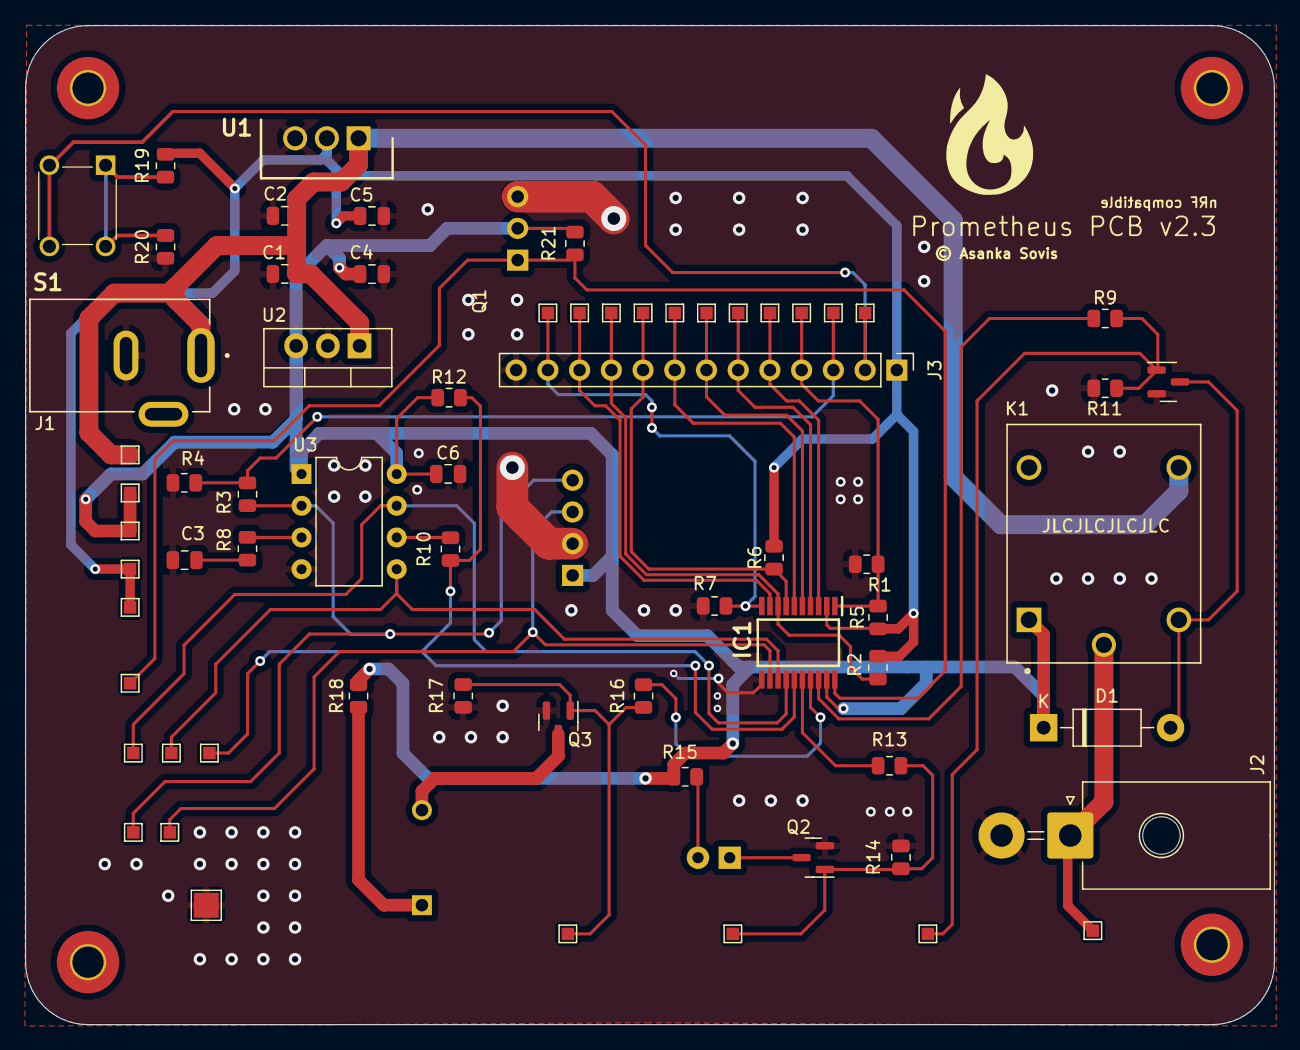
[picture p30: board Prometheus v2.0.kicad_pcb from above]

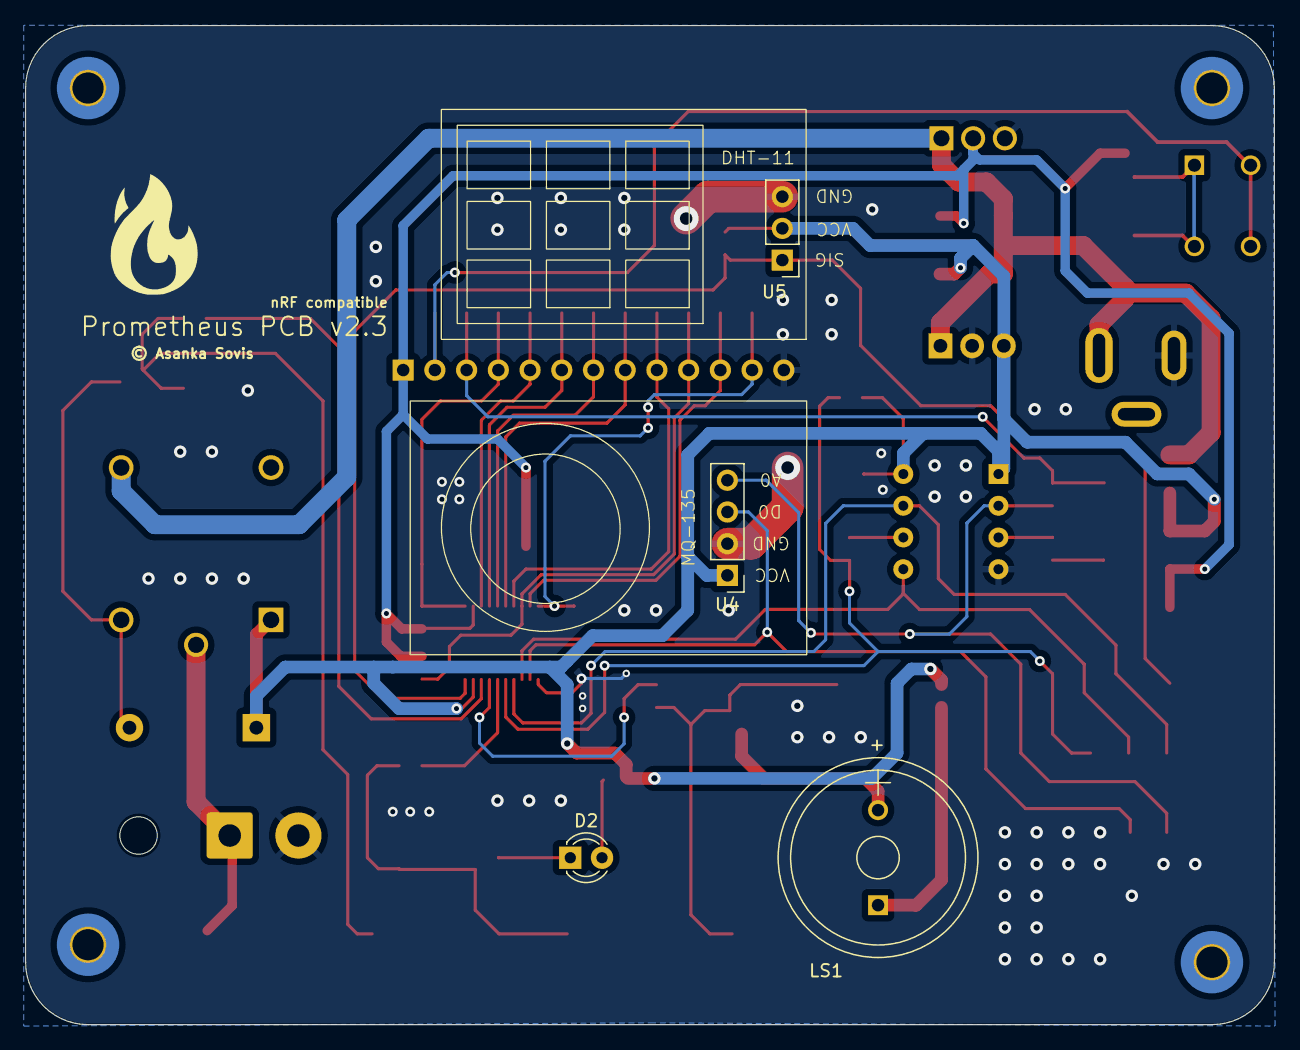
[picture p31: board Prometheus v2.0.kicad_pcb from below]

Board: 2 copper layers, 100.0 x 80.0 mm, 75 parts (4 on the bottom side), 37 nets.

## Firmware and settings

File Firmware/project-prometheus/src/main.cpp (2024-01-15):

/*
 * Copyright (c) 2021 Nordic Semiconductor ASA
 *
 * SPDX-License-Identifier: LicenseRef-Nordic-5-Clause
 */

#include "app_task.h"

#include <zephyr/logging/log.h>

LOG_MODULE_REGISTER(app, CONFIG_CHIP_APP_LOG_LEVEL);

int main()
{
	CHIP_ERROR err = AppTask::Instance().StartApp();

	LOG_ERR("Exited with code %" CHIP_ERROR_FORMAT, err.Format());
	return err == CHIP_NO_ERROR ? EXIT_SUCCESS : EXIT_FAILURE;
}

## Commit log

2023-11-04 Phase 01 - v1.0
    - Power circuitry, reset, indicators and relay
    [Prometheus v2.0.kicad_pcb, Prometheus v2.0.kicad_sch]
2023-11-04 v1.0 - Phase 2
    - Completed the complete schematic
    [Prometheus v2.0.kicad_sch]
2023-11-10 v2.1
    - First design completion
    [Prometheus v2.0.kicad_sch]
2024-01-13 Finalized Hardware
    - Finalized hardware that was printed.
2024-01-14 Bug Fixes, Documentation and Feature
    - Bug fixes for initialization check
    - Added builtin indicator to indicate device status
    - Documentation
2024-01-14 Updated BOM
    - Generated HTML BOM for the project
    [Prometheus v2.0.csv]
2024-01-15 Added Documentation files and Enclosure View
    - Added documentation files
    - Added enclosure step file and related images
2024-04-19 Added Exclude File to Git Attribute file
    .gitattribute file updated to ignore Hardware directory to ignore HTML entries in the BOM. This eliminates the issue of primary language being detected as HTML.

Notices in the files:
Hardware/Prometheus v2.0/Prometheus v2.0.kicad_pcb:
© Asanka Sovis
